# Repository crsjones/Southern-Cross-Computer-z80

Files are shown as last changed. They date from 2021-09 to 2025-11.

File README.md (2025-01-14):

# Southern Cross Computer

I developed the Z80 Southern Cross Computer for Hong Kong based Kitsrus in 1992/93.
The kit was based on the TEC-1 Computer that was designed by John Hardy and Ken Stone
in 1983 and appeared in Australia's Talking Electronics Magazine Issue 10 March 1983.

Kitsrus distributed the kit into the US and the UK and was sold online from Hong Kong.

The Southern Cross Computer appeared in Australia's Silicon Chip Magazine in the August 1993 edition.
A follow up article appeared in Silicon Chip in December 1993 describing the 8x8 LED Matrix and 8 Channel Relay add-on board.

There is a Facebook group for the Southern Cross SBC
[https://www.facebook.com/groups/1553416258519631)

### SC-8x8   8 x 8 LED Matrix
The original 8 x8 LED Matrix design plus a couple of revisions.
### SC-GBCART
An add-on board that connects a Gameboy FLASH cartridge to the Southern Cross SBC.
### SC-SERIAL 
A MC6850 serial board based on the Grant Searle 'Minimum System Z80' design.
### SC-APU
An add-on card for the AM9511A  Arithmetic Processor Unit.
### SC-MEM
Expansion memory board. 2x28 pin sockets for either 8kx8 or 32kx8 devices. 
### SC-CPU
Connect your expansion boards to this CPU board instead of the Southern Cross SBC!
### SC-BP
An expandable six slot backplane that connects to the SC expansion connector.

### SC-ALED
A hardware, parallel to serial PWM WS2812B addressable RGB LED driver board.

# Current Version

The current version of the Southern Cross PCB is 3.3, Gerbers are available in the SouthernCrossSBC_PCB_R33 folder.

The current version of the monitor is 1.8.
 Source code, listing, binary and INTEL hex files can be found in the SCMonitorV18 folder under the SouthernCrossSBC_Monitor folder.

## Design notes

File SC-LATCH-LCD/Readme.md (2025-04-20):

# Southern Cross LCD

Using a latch is a common way to connect to a LCD.
The schematic shows how to hook up a 2 line 16 character LCD (1602) to an eight bit latch.
You can hook it up to the SC I/O port at the top of the board or use IC1 to replace the multiplexed 7 segment display.

The code uses the same routines as the monitor uses for the seven segment display but outputs to the LCD instead, also sending the displayed
string out the serial port.
 
The code is a work in progress so the backlight control is currently not implemented and there 
are some additional functions needed to complete the LCD driver.

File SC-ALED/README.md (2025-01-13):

## SC-ALED

A parallel to serial converter to drive WS2812B ARGB's (Addressable RGB LED's) aka Neopixels.

This board simply accepts a byte from an I/O write and converts it to a serial bit stream of PWM pulses to set the colours in each ARGB in a string.

### SC-ALED-01Article.pdf
### SC-ALED-01ComponentOverlayBOM.pdf
### SC-ALED-01Schematic.pdf

## Folders

### ExampleCode
Code examples for the board using the SC SBC.

### Gerber
A zip file containing Gerber files for the Double-Sided TH PCB.

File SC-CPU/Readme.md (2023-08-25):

# Southern Cross CPU
A Z80 Microprocessor with a reset and oscillator circuit.
All of the Z80 pins are brought out to a 2x20 40 pin header and to a 40 pin socket for plugging into an
existing Z80 socket. A ZIF socket footprint is also provided.

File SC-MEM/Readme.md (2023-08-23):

# Southern Cross Memory Expansion

A memory expansion board that takes 2 x 28 pin devices, the board can be strapped to use
SRAM,EEPROM or EPROM devices, organised as either 8k x 8 or 32k x 8.
Decoding can be selected for each device, duplicating the memory decoding circuit on the main board for 8k decoding 
of the whole memory map or decoded as two 32k blocks.

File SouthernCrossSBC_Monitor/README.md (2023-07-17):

# Southern Cross Computer Monitor

The current version of the monitor is 1.8. 
 Source code, listing, binary and INTEL hex files can be found in the SCMonitorV18 folder under the SouthernCrossSBC_Monitor folder.
The Monitor will work on any version of the Southern Cross PCB and on the TEC-1F and also supports a software scanned keyboard
 if the out of production 74C923 keyboard encoder cannot be sourced.

It can be conditionally built for the following boards:

### SC18-SC
This is the version for a Southern Cross with a 74C923 keyboard encoder.
### SC18-SC-SS
This is the version for a Southern Cross with software scanned keyboard mods.
### SC18-TEC-1F
This is the version for the TEC-1F with a 74C923 keyboard encoder.
### SC18-TEC-1F-SS
This is the version for the TEC-1F with software scanned keyboards mods.

The source file was assembled using TASM32. There is an include (SCM18_Include.asm) file that defines all the Monitor variables 
that can be used in your own programs, an short example of its use is also included in the folder (SCMTest.asm)

### SCMonitorV18_ACIA
A version of the 1.8 Monitor has been patched with the ACIA code from the SC-6850_Serial\Code folder to work with the 6850 ACIA
instead of the Bit Bang Serial Port, only the Source file is provided.

### SCNEO
Built with Buffered Interrupt driven serial communication using the SC-SERIAL ACIA Add-on board.

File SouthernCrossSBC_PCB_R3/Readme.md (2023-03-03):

#Southern Cross Version 3.0 PCB

Changes to Version 3.0 

1. Added extra holes for 6mm sq. tactile switches.
2. Re-spaced the 7 segment LEDs to allow for FND500/560 displays.
3. Replaced the Resistor network  SIL3 with individual resistors.
4. Replaced W02 bridge with individual 1N4002 diodes.
5. Replaced 0.85" pitch electrolytic capacitor pads with 0.1" pitch pads.
6. DIN1 goes to pin 15 IC 8 and DIN2 goes to pin 17 IC8, labels were swapped on original schematic.
7. Replaced speed switch with 0.1" pads.
8. Added 0.1" pitch 2 pin connector for 5V.
9. Added top layer pad for mounting holes.
10. Added keyboard legend to silk screen.

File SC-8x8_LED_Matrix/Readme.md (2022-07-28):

# Southern Cross 8 x 8 LED Matrix Display 

### SC-8x8_R2
The version produced by Kitsrus, 
this folder contains the original manual and code.

This original documentation was downloaded from the Quasar Electronics website.

https://quasarelectronics.co.uk/Item/sc04-8x8-display-board

### SC-8x8_R3 
This version was just a redo of the original circuit on a smaller PCB, designed 
to fit behind the display.

### SC-8x8_R4 
The manual contains the schematic, bill of material(s) and component overlay.

PCB Gerbers are provided for this version.

The code is from the original distribution disk and can be assembled using TASM.

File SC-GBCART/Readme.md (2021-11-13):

# Southern Cross GB Cart Adapter

Some bootleg GameBoy cartridges use 4M FLASH chips and 32k SRAM's.
They can be connected directly to the Z80 buses and can be re-flashed using one of the GameBoy  
flashers that are available.

As the cartridge maps across most of the memory map you need to remove the EEPROM and 
RAM from the Southern Cross, you can however connect the EEPROM and RAM socket to the 
undecoded areas of the memory map $8000-$9FFF, $C000- $DFFF and $E000-$FFFF.
You could use both sockets with RAM  with some small modifications to the PCB. 
This will give a total of 24k bytes of RAM in the memory map, with 8k banked as described below.

The Gerbers for the PCB are provided, remember to specify the PCB as 0.8mm thick otherwise the IDC
 connector won't fit over the edge of the PCB.

The information about the cart was supplied to the TEC-1 Z80 Facebook group by Ben Grimmett;
He sells the Flash Cartridges on his website;  https://bennvenn.myshopify.com/

4M FLASH / 32K (NVRAM) SRAM cartridge. MBC5 Mapper.

Memory map:

0x0000-0x3FFF:    16kBytes - fixed to Flash Address 0x0000-0x3FFF

0x4000-0x7FFF:    16kBytes - 4MBytes in 256 banks, swapped by writing to address 0x2000.

0xA000-0xBFFF:    8kBytes - 32kBytes in 8k banks, swapped by writing to 0x4000.

                 Write protected unless 0x0A written to 0x0000. Protected if any other value is written to that address.

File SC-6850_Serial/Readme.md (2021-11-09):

# Southern Cross Serial

This circuit is based on the “Minimum chip count z80 computer” design by Grant Searle and is commonly used in the RC2014 project.

Here it has been adapted for the Southern Cross Computer adding the expansion connector, I/O decoding, 
and a header for a FTDI USB to serial converter.

Version 2  has an additional jumper to disconnect the INT interrupt signal from the processor, the CLK INT jumper has been

renamed OSC. Some designators have been renamed.

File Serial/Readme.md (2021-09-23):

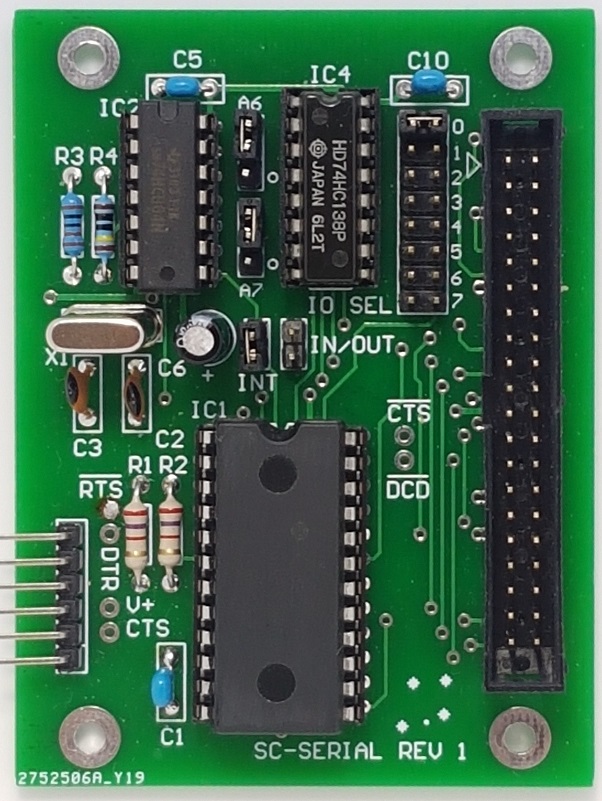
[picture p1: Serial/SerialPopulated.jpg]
SC Serial Board


# Southern Cross Serial

This circuit is based on the “Minimum chip count z80 computer” design by Grant Searle and is commonly used in the RC2014 project.

Here it has been adapted for the Southern Cross Computer adding the expansion connector, I/O decoding, 
and a header for a FTDI USB to serial converter.

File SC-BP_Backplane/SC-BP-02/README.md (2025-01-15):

## SC-BP Six Slot Backplane 

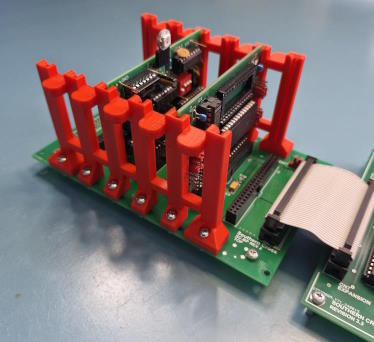
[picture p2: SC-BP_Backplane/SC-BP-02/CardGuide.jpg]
Southern Cross Backplane


The Backplane board allows the expansion of the Southern Cross SBC, the 40 way Box header on the main board brings out all of the Z80 pins.

You can also use the backplane with the processor board, a expansion memory board and a serial port board to create a stand-alone "rack" system.

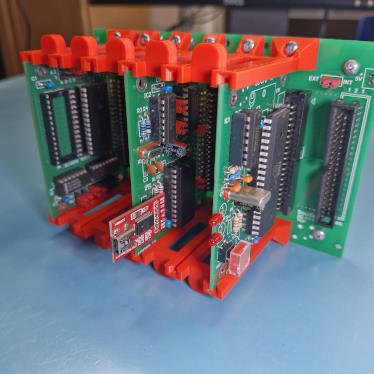
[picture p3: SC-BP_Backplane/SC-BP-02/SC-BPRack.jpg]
Southern Cross Rack Mount


Included in this folder is the .STL file for the card guide.

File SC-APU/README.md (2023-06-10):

### SC-APU

This add-on board was created for Stephen Justin of the TEC-1 Facebook group https://www.facebook.com/groups/tec1z80 and
inspired by Philip Stevens' RC2014 APU https://github.com/RC2014Z80/RC2014/tree/master/Hardware/APU%20RC2014

There are two code examples, the first, SC-LLL-FP is a purely software demonstration of the "Lawrence Livermore Laboratory Floating Point Package".
I have a separate repository with more info about this code.

The second code example, AM9511A uses the APU to perform basic arithmetic operations.
To run the code on the APU you need to be using the Southern Cross Monitor 1.8 as it uses the monitor system calls.

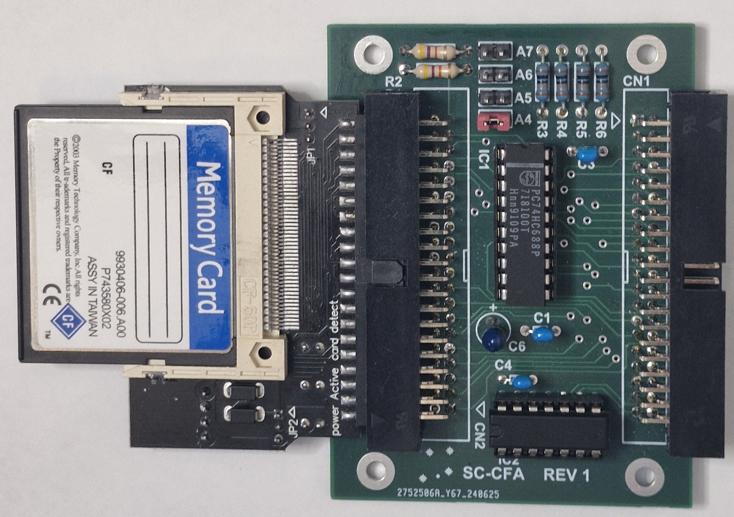
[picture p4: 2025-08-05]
SC-CF/CardwithCF.jpg

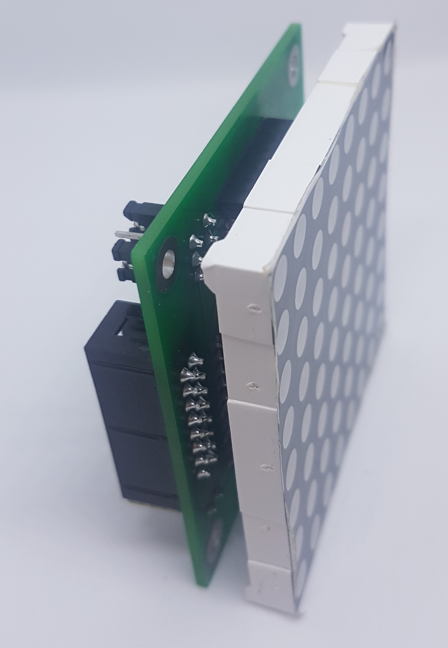
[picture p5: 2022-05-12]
SC-8x8_LED_Matrix/SC-8x8_R3/SC-8x8-R3-1.jpg

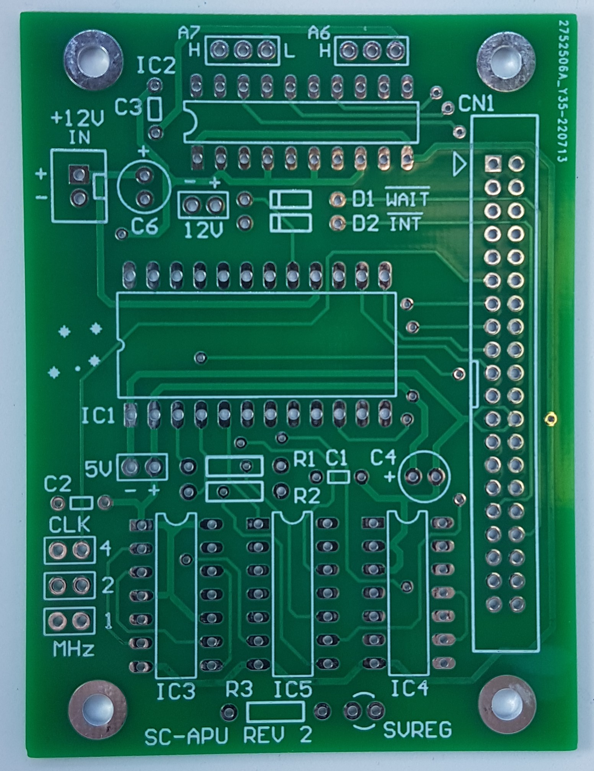
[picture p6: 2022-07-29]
SC-APU/SC-APU-R2/SC-APU-R2_PCB.jpg

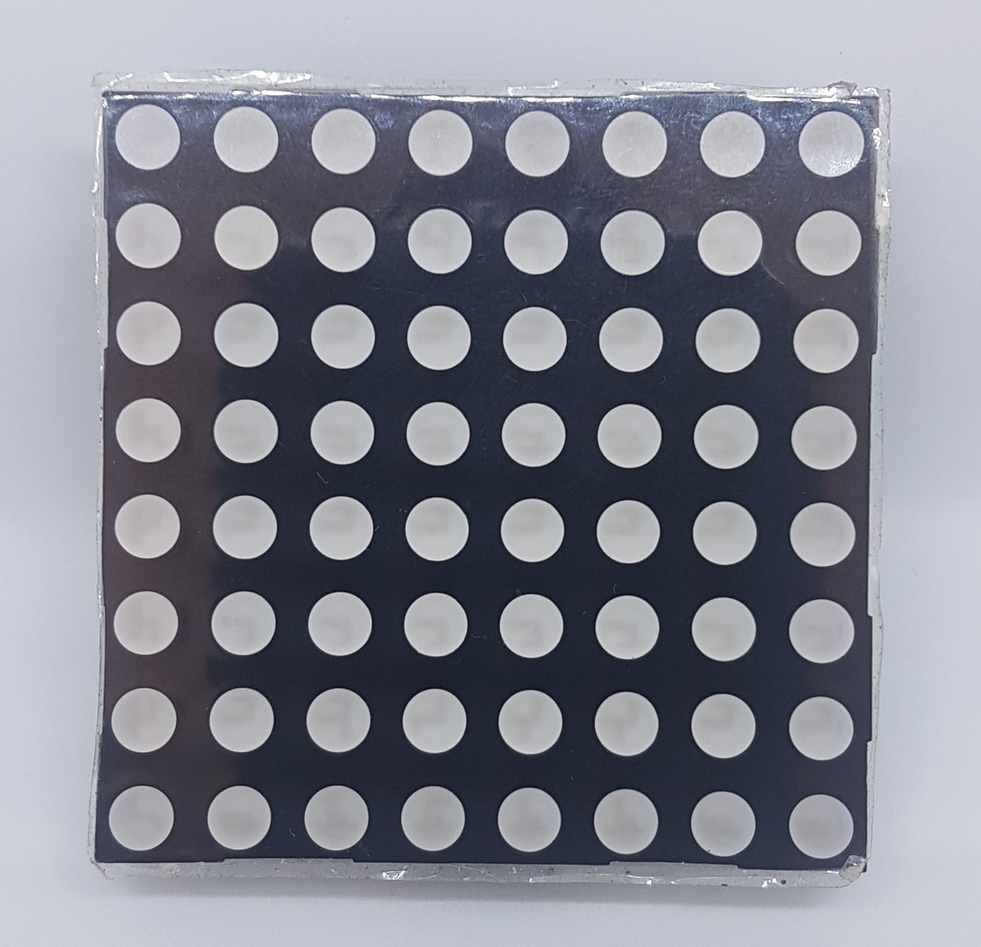
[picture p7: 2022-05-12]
SC-8x8_LED_Matrix/SC-8x8_R3/SC-8x8-R3-2.jpg

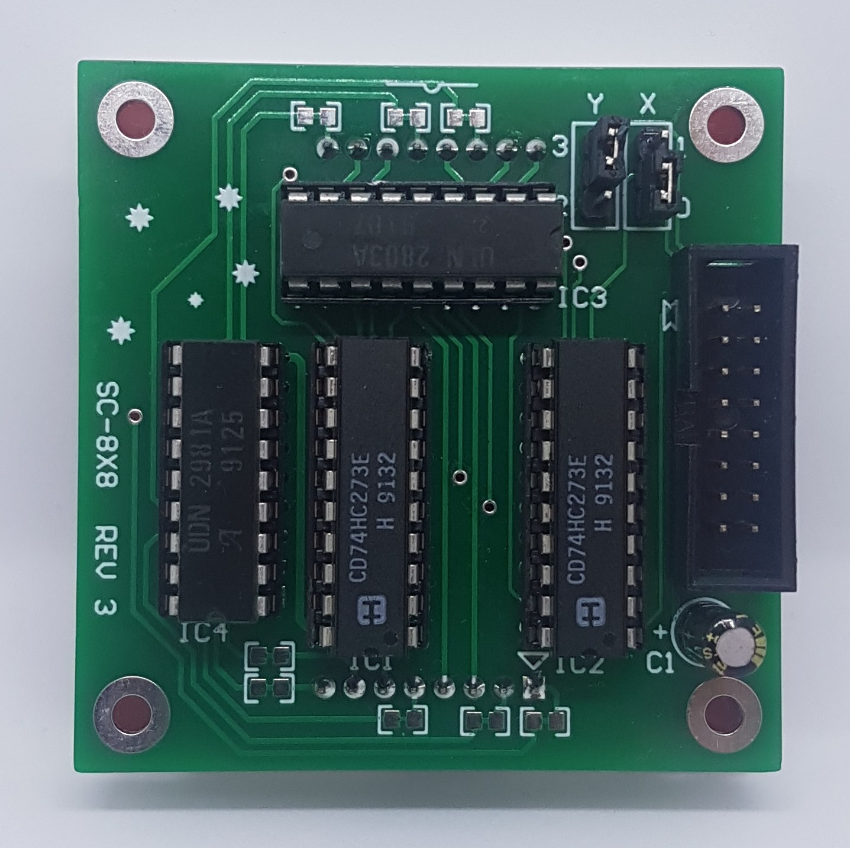
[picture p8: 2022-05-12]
SC-8x8_LED_Matrix/SC-8x8_R3/SC-8x8-R3.jpg

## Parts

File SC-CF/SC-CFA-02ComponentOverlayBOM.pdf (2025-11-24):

## SC-CFA Compact Flash Adapter Rev. 2

## Component Overlay

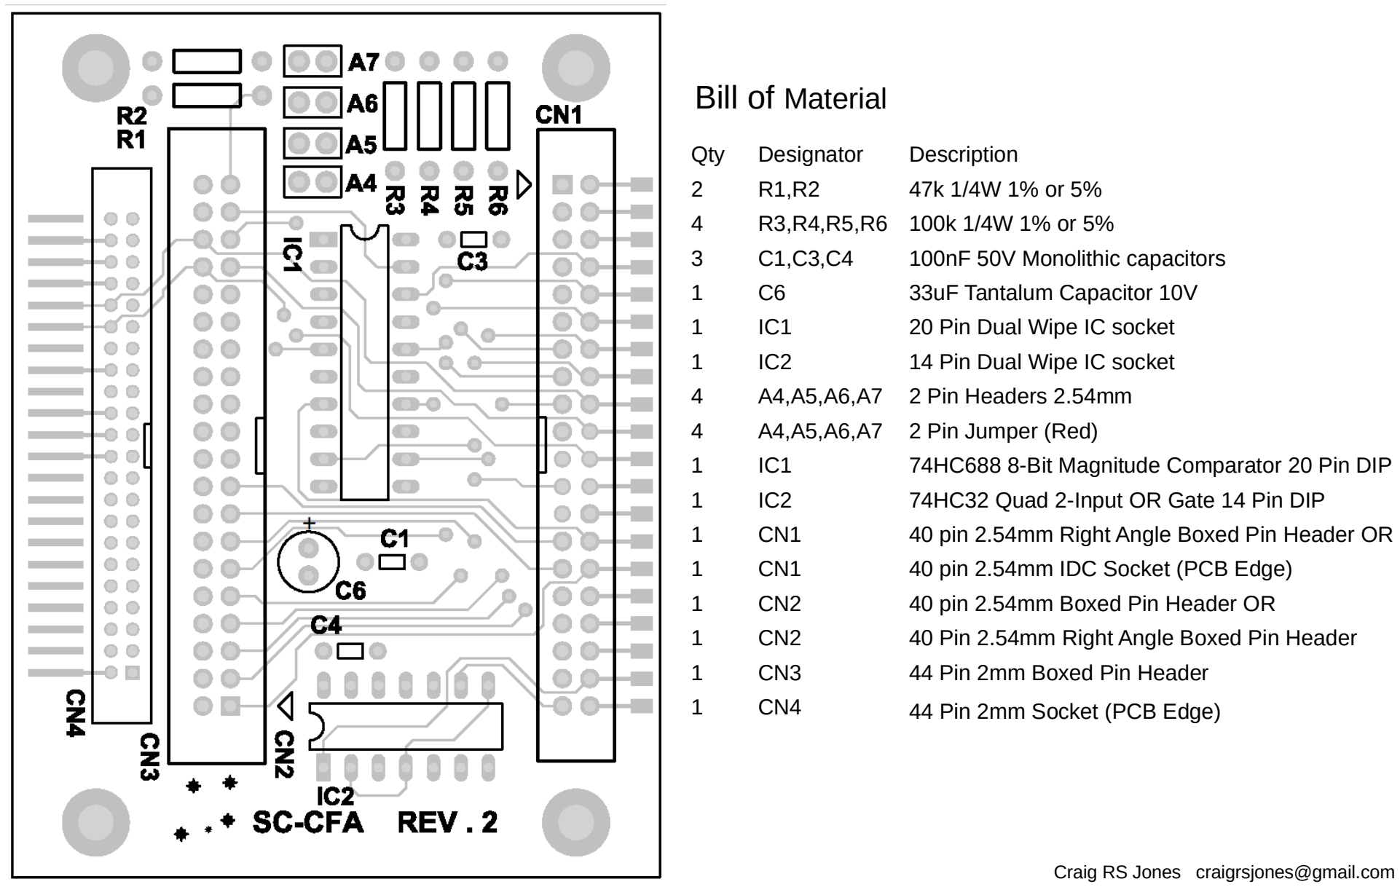
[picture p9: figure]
Bill of Material; Craig RS Jones craigrsjones@gmail.com; Qty; Designator; Description; 100nF 50V Monolithic capacitors; 33uF Tantalum Capacitor 10V; 20 Pin Dual Wipe IC socket; 14 Pin Dual Wipe IC socket; 2 Pin Headers 2.54mm; 2 Pin Jumper (Red); 40 pin 2.54mm Boxed Pin Header OR; 44 Pin 2mm Boxed Pin Header; 44 Pin 2mm Socket (PCB Edge)

1 | IC1 | 74HC688 8-Bit Magnitude Comparator 20 Pin DIP
1 | IC2 | 74HC32 Quad 2-Input OR Gate 14 Pin DIP
1 | CN1 | 40 pin 2.54mm Right Angle Boxed Pin Header OR
1 | CN1 | 40 pin 2.54mm IDC Socket (PCB Edge)
1 | CN2 | 40 Pin 2.54mm Right Angle Boxed Pin Header

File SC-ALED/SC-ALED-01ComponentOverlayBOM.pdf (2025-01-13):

## SC-ALED Addressable LED Interface Rev. 1

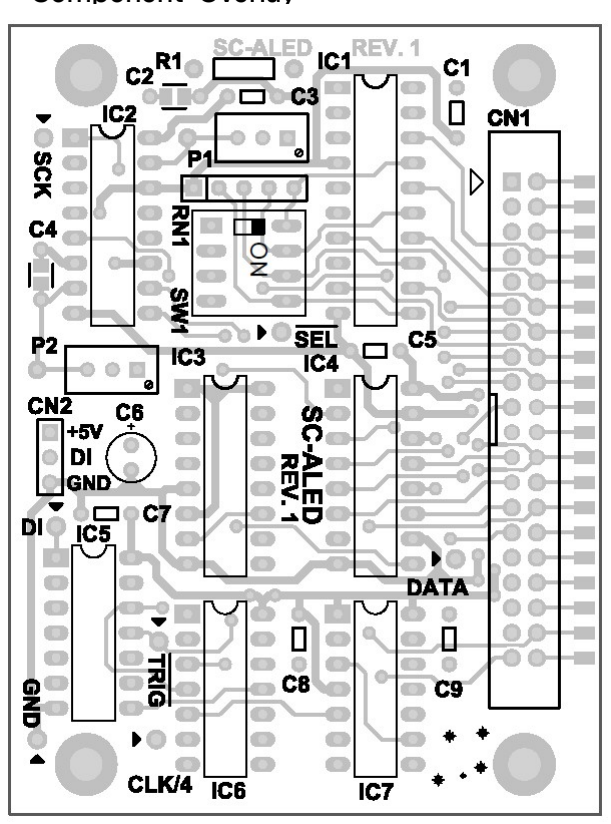
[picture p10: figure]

Component Overlay | Bill of Material

craigrsjones@gmail.com

Qty | Designator | Description
1 | R1 | 100R 1/4W 5% Resistor
1 | P1 | 2k2 1/4W 1% Resistor OR 10 Turn Trimpot 10k Bourns 3296 or Equivalent
1 | P2 | 5k6 1/4W 1% Resistor OR 10 Turn Trimpot 10k Bourns 3296 or Equivalent
1 | RN1 | Resnet 5 pin, 4 Commoned 100k Resistors SIL5
6 C1,C3,C5,C7, | C8,C9 | 100nF 50V X7R Monolithic Ceramic Capacitors (MLCC) 5mm Pitch
2 | C2,C4 | 100pF 50V 5% NPO/C0G MLCC Capacitor 0805 SMD OR 5mm Through Hole (TH)
1 | C6 | 10uF 50V Electrolytic Capacitor 2.54mm Pitch
1 | IC1 | 20 Pin Dual Wipe IC Socket
3 | IC2,IC3,IC4 | 16 Pin Dual Wipe IC Socket
3 | IC5,IC6,IC7 | 14 Pin Dual Wipe IC Socket
1 | IC1 | 74HC688 8-Bit Magnitude Comparator 20 Pin DIP
1 | IC2 | 74HC221 Dual Monostable 16 Pin DIP
1 | IC3 | 74HC161 Synchronous Binary Counter DIP 16
1 | IC4 | 74HC165 8-Bit Parallel Load Shift Register DIP 16
1 | IC5 | 74HC02 Quad 2-Input NOR Gate DIP 14
1 | IC6 | 74HC00 quad 2-Input NAND Gate DIP 14
1 | IC7 | 74HC74 Dual D Flip-Flop 14 Pin DIP
1 | SW1 | 4-Way DIP Switch
1 | CN1 | 40 pin 2.54mm Right Angle Boxed Pin Header
1 | CN2 | 3 Way R/A Pin Header

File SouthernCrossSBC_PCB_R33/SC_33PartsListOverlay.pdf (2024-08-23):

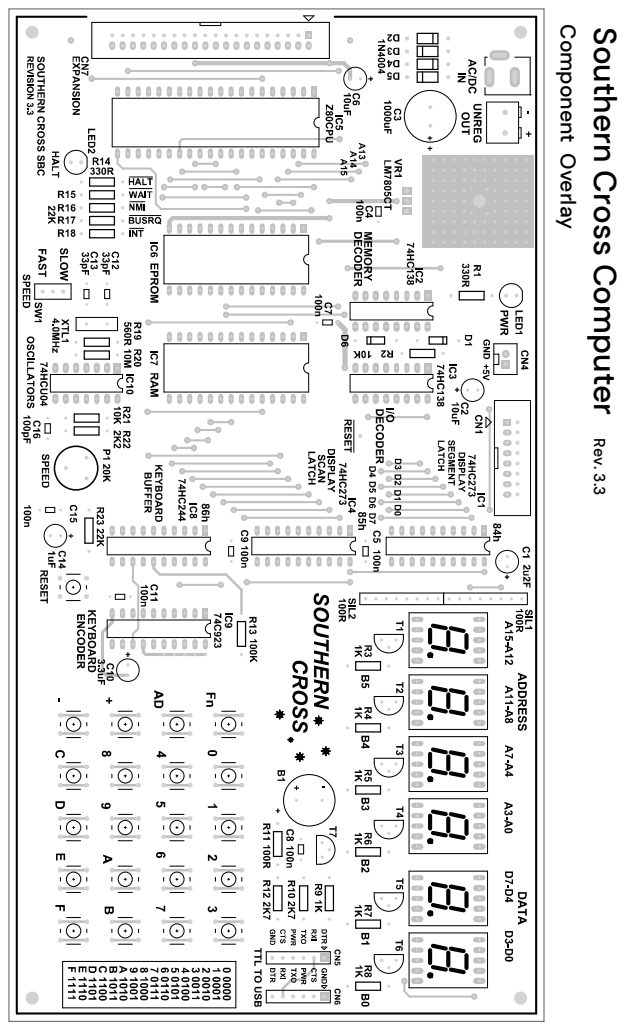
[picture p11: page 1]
Component Overlay

Southern Cross Computer Rev. 3.3

## Bill of Material

# Southern Cross Computer Rev. 3.3

Connued

Qty | Designator | Description
2 | R1,R14 | 330R ¼ W 5% Resistor
1 | R2,R21 | 10k ¼ W 5% Resistor
7 | R3,R4,R5,R6,R7,R8,R9 | 1k ¼ W 5% Resistor
2 | R10,R12 | 2k7 ¼ 5%W Resistor
1 | R11 | 100R ¼ W 5% Resistor
1 | R13 | 100k ¼ W 5% Resistor
5 | R15,R16,R17,R18,R23 | 22k ¼ W 5% Resistor
1 | R19 | 560R ¼ W 5% Resistor
1 | R20 | 10M ¼ W 5% Resistor
1 | R22 | 2k2 ¼ W 5% Resistor
2 | SIL1,SIL2 | 100R Resistor Network 8 Pin 4 Individual Resistors
4 | D2,D3,D4,D5 | 1N4004 Diode
2 | D1,D6 | 1N4148, 1N914 Small Signal Diode
1 | IC10 | 14 Pin Dual Wipe IC Socket
2 | IC2,IC3 | 16 Pin Dual Wipe IC Socket
4 | IC1,IC4,IC8,IC9 | 20 Pin Dual Wipe IC Socket
2 | IC6,IC7 | 28 Pin Dual Wipe IC Socket
1 | IC5 | 40 Pin Dual Wipe IC Socket
1 | C1 | 2u2F 50V Electrolytic Capacitor
2 | C2,C6 | 10uF 50V Electrolytic Capacitor
1 | C3 | 1000uF 35V Electrolytic Capacitor
7 | C4,C5,C7,C8,C9,C11,C15 | 100nF 50V Monolithic Ceramic Capacitor
1 | C10 | 3u3F 50V Electrolytic Capacitor
2 | C12,C13 | 33pF 50V Monolithic Ceramic Capacitor
1 | C14 | 1uF 50V Electrolytic Capacitor
1 | C16 | 100pF 50V Monolithic Ceramic Capacitor
7 | T1,T2,T3,T4,T5,T6,T7 | NPN Transistor BC337 40V TO-92 General Purpose
6 | LD1,LD2,LD3,LD4,LD5,LD6 | 0.56” 7 Segment LED Display, Common Cathode
2 | LED1,LED2 | 3mm Red LED
1 | CN1 | Straight Box Header, 16 Way 2 x 8 Rows
1 | CN2 | Power Jack for Barrel Connector O.D. 5.5 / I.D. 2.1 mm
1 | CN3 | 2 Way Screw Terminal Block
1 | CN4 | 2 Way 0.1” / 2.54mm Pin Header
1 | CN5 or CN6 | 6 Way 0.1” / 2.54mm Pin Header
1 | CN7 | Straight Box Header 40 Way 2 x 20 Rows
1 | SW1 | 3 Way 0.1” / 2.54mm Pin Header + Shunt

Bill of Material Continued

# Southern Cross Computer Rev. 3.3

NOTES:
1. Designators Increment from the top left to right, top to bottom of the PCB.

### 2. The MM74C923 is obsolete and no longer manufactured, however they can still be found

on Ebay.
Alternatively you can use the software scanned keyboard built into the monitor and not use a MM74C923 at all. There is a modification procedure in this folder.
Qty | Designator | Description
21 S1,S2,S3,S4,S5,S6,S7,S8,S9, | S10,S11,S12,S13,S14,S15,S16, S17,S18,S19,S20,S21 | Pushbuttons, Tactile Switch OMRON B3F 6mm
1 | P1 | 20k VTP Cermet Trimpot
1 | B1 | Mini Magnetic Transducer 0.25” 6.35mm
1 | VR1 | LM7805CT 5V Fixed Voltage Regulator TO-220
1 | XTL1 | 4MHz Crystal HC49 / HC49U
1 | VR1 | TO-220 Heatsink 19 x 15 x 10 mm M3x8 Machine Screw Zn, M3 Hex Nut Zn, M3 split washer.
2 | IC1,IC4 | 74HC273 Octal D Flip-Flops with Clear
2 | IC2,IC3 | 74HC138 3-to-8 Line Decoder
1 | IC5 | Z84C0008PEG CMOS Z80 CPU 8MHz 40 pin DIP
1 | IC6 | AT28C64B-15PU 8k x 8 DIP28 EEPROM
1 | IC7 | 6264 8k x 8 DIP28 SRAM
1 | IC8 | 74HC244 Octal TRI-STATE Buffer DIP20
1 | IC9 | MM74C923N 20 Key Keyboard Encoder DIP20
1 | IC10 | 74HCU04 Hex Inverter
1 | PCB | PCB Southern Cross SBC Revision 3.3

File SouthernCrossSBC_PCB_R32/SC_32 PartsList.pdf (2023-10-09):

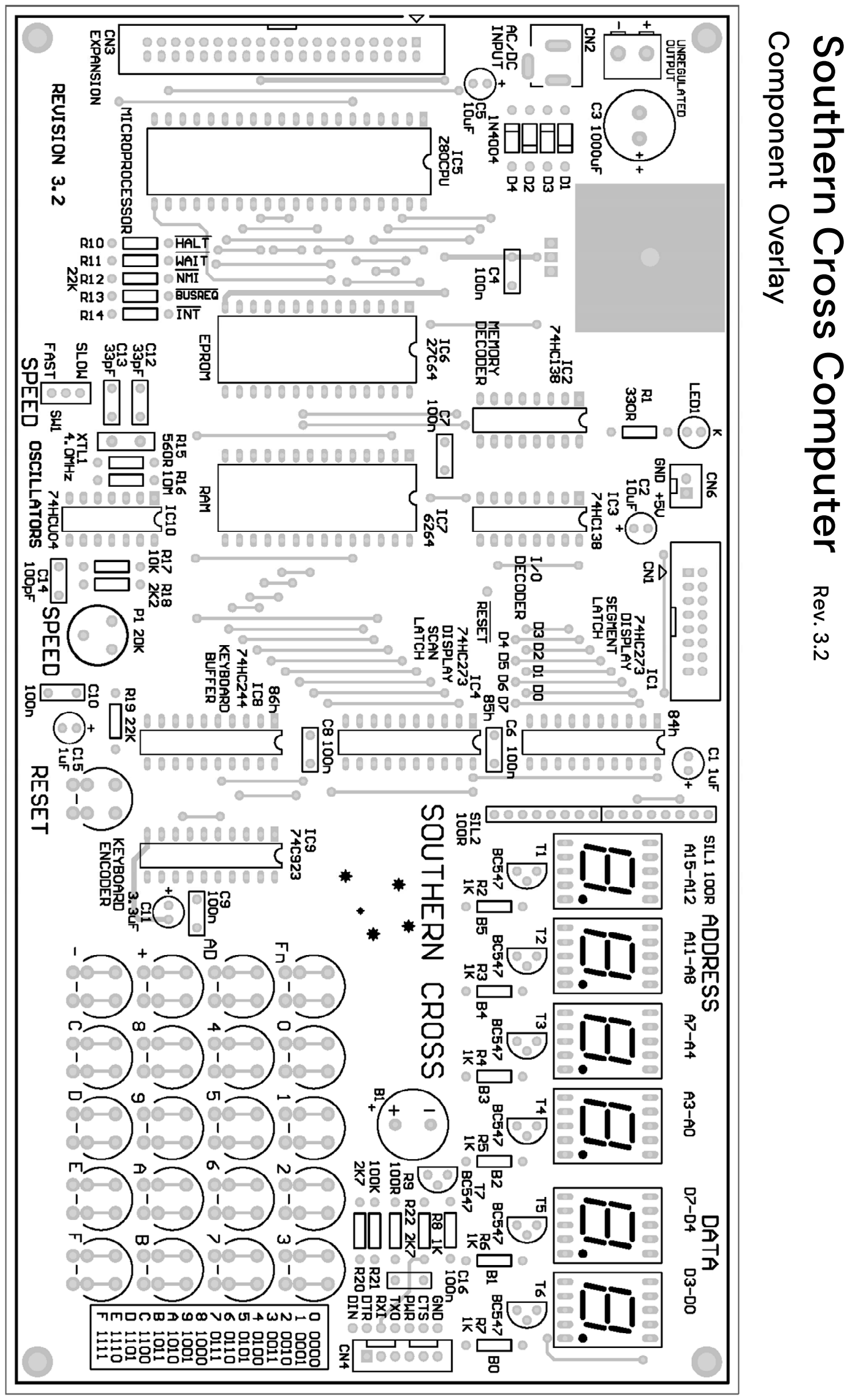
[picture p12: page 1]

# Southern Cross Computer Rev. 3.2

## Component Overlay

## Bill of Material

# Southern Cross Computer Rev. 3.2

Qty | Designator | Description
1 | R1 | 330R 1/4W Resistor
7 | R2,R3,R4,R5,R6,R7,R8 | 1k 1/4W Resistor
1 | R9 | 100R 1/4W Resistor
6 | R10,R11,R12,R13,R14,R19 | 22k 1/4W Resistor
1 | R15 | 560R 1/4W Resistor
1 | R16 | 10M 1/4W Resistor
1 | R17 | 10k 1/4W Resistor
1 | R18 | 2k2 1/4W Resistor
2 | R20,R22 | 2k7 1/4W Resistor
1 | R21 | 100k 1/4W Resistor
4 | D1,D2,D3,D4 | 1N4004 Diode
1 | IC10 | 14 Pin Dual Wipe IC Socket
2 | IC2,IC3 | 16 Pin Dual Wipe IC Socket
4 | IC1,IC4,IC8,IC9 | 20 Pin Dual Wipe IC Socket
2 | IC6,IC7 | 28 Pin Dual Wipe IC Socket
1 | IC5 | 40 Pin Dual Wipe IC Socket
2 | C1,C15 | 1uF 0.1” / 2.54mm
2 | C2,C5 | 10uF 25V
1 | C3 | 1000uF 25V / 35 V
7 | C4,C6,C7,C8,C9,C10,C16 | 100nF 50V
1 | C11 | 3u3F 63V
2 | C12,C13 | 33pF Monolithic Ceramic 100V
1 | C14 | 100pF Monolithic Ceramic 100V
6 | LD1,LD2,LD3,LD4,LD5,LD6 | 0.56” 7 Segment LED Display, Common Cathode
7 | T1,T2,T3,T4,T5,T6,T7 | NPN Transistor TO-92 General Purpose
1 | CN1 | Straight Box Header, 16 Way 2 x 8 Rows
1 | CN2 | Power Jack for Barrel Connector O.D. 5.5 / I.D. 2.1 mm
1 | CN3 | Straight Box Header 40 Way 2 x 20 Rows
1 | CN4 | 6 Way 0.1” / 2.54mm Pin Header
1 | CN5 | 2 Way Screw Terminal Block
1 | CN6 | 2 Way 0.1” / 2.54mm Pin Header
1 | SW1 | 3 Way 0.1” / 2.54mm Pin Header + Shunt

Connued

Qty | Designator | Description
21 S1,S2,S3,S4,S5,S6,S7,S8,S9, | S10,S11,S12,S13,S14,S15,S16, S17,S18,S19,S20,S21 | Pushbuttons, Tactile Switch OMRON B3F 6mm or C&K Momentary Keyswitch D6 5mm
2 | SIL1,SIL2 | 4 x 100R Isolated Resistor Network 8 Pin SIL (Single In Line) or 4 x 100R 1/4W Resistor mounted upright
1 | LED1 | 3mm Red LED
1 | P1 | 20k Trimpot
1 | B1 | Mini Magnetic Transducer 0.25” 6.35mm
1 | VR1 | LM7805CT 5V Fixed Voltage Regulator TO-220
1 | XTL1 | 4MHz Crystal HC49 / HC49U
1 | HS1 | TO-220 Heatsink M3x10 Machine Screw Zn, M3 Hex Nut Zn, M3 split washer.
2 | IC1,IC4 | 74HC273 Octal D Flip-Flops with Clear
2 | IC2,IC3 | 74HC138 3-to-8 Line Decoder
1 | IC5 | Z80 CPU
1 | IC6 | 27C64 8k x 8 EPROM or AT28C64A EEPROM
1 | IC7 | 6264 8k x 8 SRAM
1 | IC8 | 74HC244 Octal TRI_STATE Buffer
1 | IC9 | MM74C923N 20 Key Keyboard Encoder *Note3
1 | IC10 | 74HCU04 Hex Inverter

Bill of Material Continued

# Southern Cross Computer Rev. 3.2

NOTES:
1. Designators Increment from the top left to right, top to bottom of the PCB. (apart from the additional resistors added to this version R20, R21, R22 which are
located near CN4)
2. Voltage Regulator VR1 is loaded on the top of the PCB above C4.

### 3. The MM74C923 is obsolete and no longer manufactured, however they can still be found

on Ebay.
Alternatively you can use the software scanned keyboard built into the monitor and not use a MM74C923 at all. There is a modification procedure for the board in the docs folder.

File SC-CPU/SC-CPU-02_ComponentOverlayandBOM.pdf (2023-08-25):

# SC-CPU Rev. 2

Component Overlay | Bill of Material

Craig RS Jones craigrsjones@gmail.com

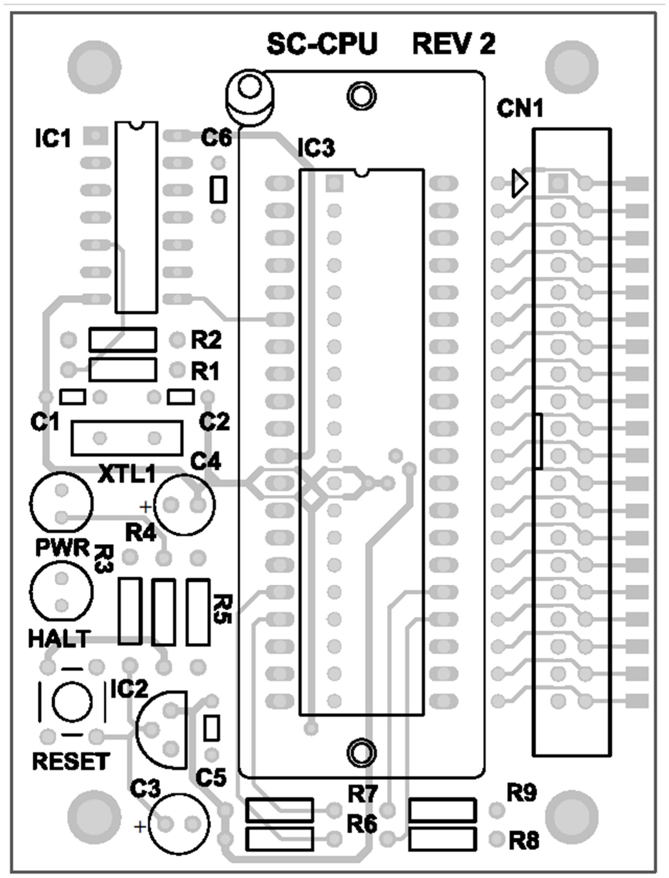
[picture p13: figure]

There are many construction options possible for this PCB, see the schematic for information on the Oscillator and Reset options. Multiple Optional components are listed here.

Qty | Designator | Description
1 | R1 | 10M 1/4W 1% or 5% (not critical)
1 | R2 | 560R 1/4W 1% or 5% (not critical)
1 | R3 | 22k 1/4W 1% or 5% (not critical)
1 | R4,R5 | 330R 1/4W 1% or 5% (not critical)
4 | R6,R7,R8,R9 | 10k 1/4W 1% or 5% (not critical)
2 | C1,C2 | 33pF 100V Ceramic capacitor 0.2” pitch
1 | C3 | 1uF RB 16vW Electrolytic Capacitor 0.1” pitch
1 | C4 | 10uF RB 16vW Electrolytic Capacitor 0.1” pitch
2 | C5,C6 | 100nF 50V Monolithic capacitors
1 | XTL1 | 4.0MHz Crystal HC49/HC49U
1 | IC1 | 14 pin Dual Wipe IC socket
1 | IC1 | 74HCU04 Hex Unbuffered Inverter 14 Pin DIP
1 | IC1 | 14 Pin Oscillator Module
1 | IC1 | 8 Pin Oscillator Module
1 | IC2 | DS1233-5 5V EconoReset TO-92
1 | IC3 | 40 Pin Dual Wipe IC socket
1 | IC3 | 40 Pin ZIF socket
2 | IC3 | 20 Pin Header strip (2 x 20 pins)
1 | IC3 | Z80 CPU 40 Pin DIP
1 | CN1 | 40 way Straight or R/A IDC box header
1 | RESET | Tactile Switch OMRON B3F 6mm
2 | PWR,HALT | 3mm / 5mm Red LED

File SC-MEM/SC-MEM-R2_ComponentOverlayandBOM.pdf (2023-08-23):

# SC-MEM Expansion Memory Rev. 2

Component Overlay | Bill of Material

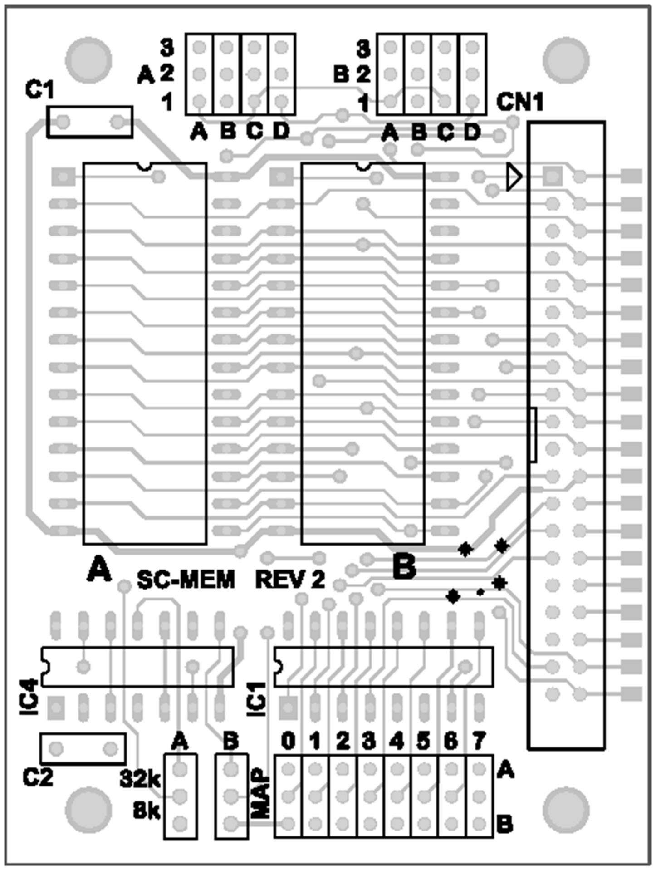
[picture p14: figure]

Craig RS Jones craigrsjones@gmail.com

Qty | Designator | Description
2 | C1,C2 | 100nF 50V Monolithic capacitors
1 | CN1 | 40 way Straight or R/A IDC box header
1 | IC1 | 16 pin Dual Wipe IC socket (optional)
1 | IC1 | 74HC138 3 to 8-line decoder 16 pin DIP
2 | IC2,IC3 | 28 pin Dual Wipe IC socket
1 | IC4 | 14 pin Dual Wipe IC socket
1 | IC4 | 74HC04 Hex Inverter DIP 14
2 J4,J5 | ‘Device Select’ | 4 x 3 Pin 0.1” pitch pin headers
1 J1 | ‘8k Memory Map Select’ | 8 x 3 pin 0.1” pitch pin headers
2 | J2,J3 | 1 x 3 pin 0.1” pitch pin headers

12 2 Pin Shunts

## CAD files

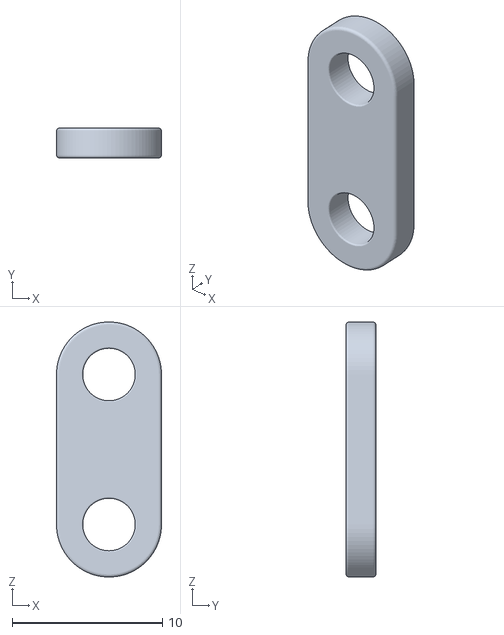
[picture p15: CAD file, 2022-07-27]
SC-8x8_LED_Matrix/SC-8x8_R4/Link.stl
7.00 x 2.00 x 17.0

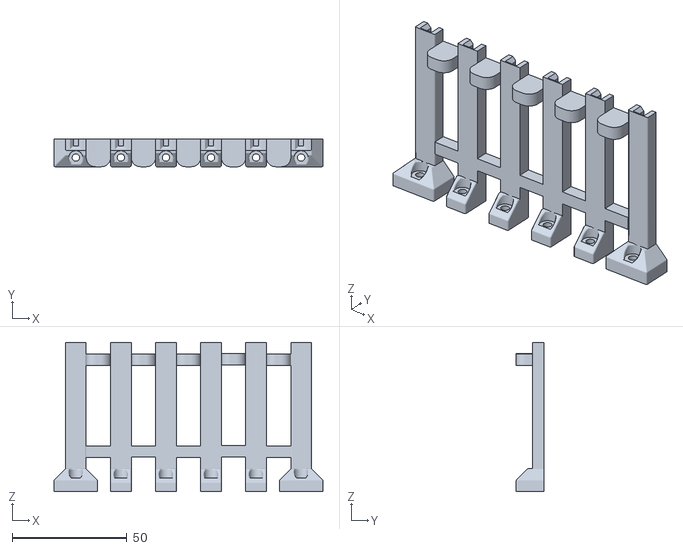
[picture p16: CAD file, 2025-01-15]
SC-BP_Backplane/SC-BP-02/SC-BPCardGuide.stl
117.0 x 12.0 x 65.0

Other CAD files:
SC-LATCH-LCD/SC-LatchLCD.obj

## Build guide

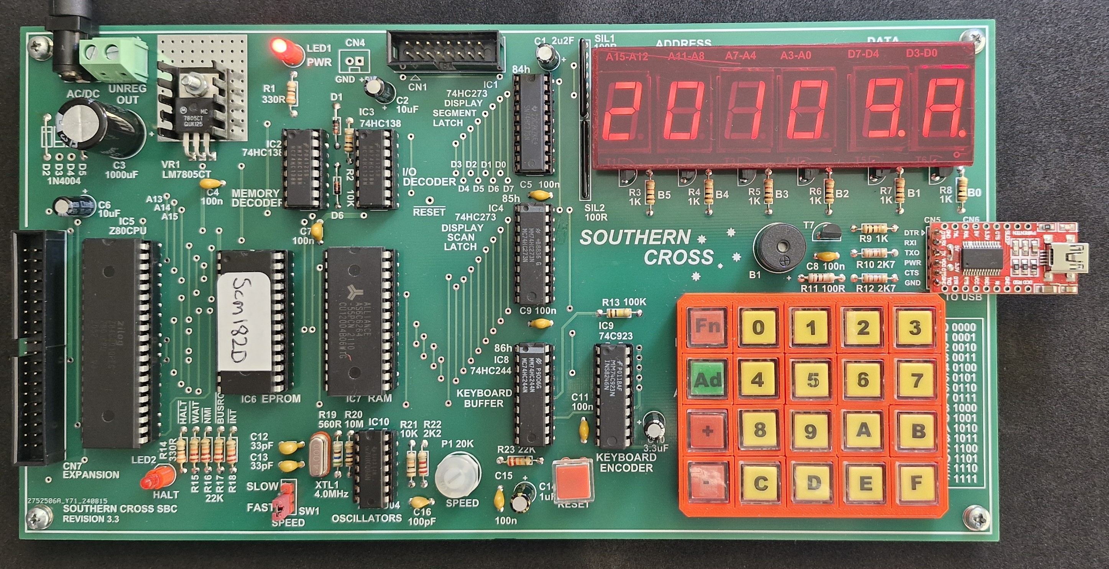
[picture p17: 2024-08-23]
SouthernCrossSBC_PCB_R33/SC33Assembled.jpg

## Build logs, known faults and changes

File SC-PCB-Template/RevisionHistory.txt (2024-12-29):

----------------------------------------------------------------------------------------------------------
2024-12-29  SC_Template_5

SC_footprint.pretty\EDGE40.kicad_mod
Removed stubs from edge connector component.
Increased pad sizes for pins 19 to 25 to 70mils up from 62 mils

SC_footprint.pretty\IDC40EDGE.kicad_mod
Removed stubs from combined IDC40EDGE edge connector component.
Increased pad sizes for pins 19 to 25 to 70mils up from 62 mils

SC_Template_5.kicad_Sch
Removed the picture of the SC expansion connector.
Renamed /BUSREQ as /BUSRQ
Renamed /BUSACK as /BUSAK

SC_Template_5.kicad_Pcb
Updated the footprints and the nets from the Schematic document to correct Net names and duplicate /BUSAK
---------------------------------------------------------------------------------------------------------

2024-12-30 SC-Template
Moved to Github repository

SC_Template.kicad_Pcb
Updated footprints to remove stubs.
---------------------------------------------------------------------------------------------------------

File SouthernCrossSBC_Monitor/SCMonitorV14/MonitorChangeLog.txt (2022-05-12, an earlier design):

Southern Cross Monitor Version 1.2
----------------------------------

Changes to Southern Cross Monitor Version 1.1   February, 1993.

1. When the Function Key is pressed twice, the routine jumps to the
address loaded at FUNJMP. It is set to CANCEL in the Fn routine and is
reloaded after Reset.

2. The table in the Function routine is now accessed by pointer FUNTBL
this will allow users to change the Function key assignments. It is set to
FUNLST (the Function key table) and is reloaded after Reset.

3. RAMCHK has been renamed as DALLAS as it is used in the Dallas
Smartwatch routines.

4. Read and write Smartwatch have had more explanation added to the
subroutine headers.

5. The Default serial BAUD rate is now 4800 Baud, which is reloaded after
Reset.

6. IO7 has been added as it is now used for the Single Stepper Hardware.

7. CALMDE has been added to the Smartwatch registers, if bit 7 is high the
calendar (Fn F) shows the date in MM/DD/YY mode, if bit 7 is low it is
shown in DD/MM/YY. This allows the setting of the date in the Smartwatch
to the country preference.

8. DELAYR has been renamed DELONE.

9. The Relay test program is now Fn D and not Fn 7.

10. Fn 7 is used to toggle the hardware single stepper if attached.It
displays a T in the rightmost Data display briefly to indicate the Trace
toggle.

11. All of the Relay code has been moved above to Fn D.
 (All the code for each function key is now in order).

12. Corrected spelling of 'Separate'

                      - - - - - - - - - - - - - - -

July, 1993.  Version 1.21
-------------------------

A buyer rang to point out that the relay test did not test all relays. We
found that a 05H instead of 55H at 0B7D in the Monitor was to blame. The
test was missing relay positions D4 and D6.

                      - - - - - - - - - - - - - - -

February 2003. Version 1.3  (This version was UNRELEASED)
--------------------------

The 74C923 code was removed and replaced with software scanned keyboard code.

1. Added SYSFLG at 3FB3H 'System Flags' 
Bit 1 is used to indicate the type of keyboard.
  
Bit 1 = 1 Software scanned keyboard.
Bit 1 = 0 Hardware scanned keyboard.

Initialization routine checks if DA is high ( software scanned keyboard
has DA tied high to allow for detection) and sets Bit 1 accordingly.

2. Added SCANKEY routine to scan keyboard, replaced all
 
IN      A,(KEYBUF) with 

with

CALL    SCANKEY

except for the increment/ decrement key handling which required some additional mods.
Added SCANKEY to system call jump table.

                      - - - - - - - - - - - - - - -

March 2021 Version 1.4
----------------------

1. Cleared SYSFLG on Reset and changed the keyboard flag to bit 0.

2. The receive INTEL hex routine did not work in the 1.3 version.
   The RXDATA routine had a cancel feature allowing a keypress to break out of the 'waiting for serial character' loop. 
   The SCANKEY routine takes a lot longer than IN  A,(KEYBUF) so the receive INTEL hex routine was now not fast enough to process incoming bytes.
   The cancel functionality was removed from the RXDATA routine, the receive INTEL hex routine now just returns to the monitor if the file download was
   successful.
   
3. The Receive INTEL Hex routine (INTELH) was made stand alone and added to the system call jump table so it could be called from outside the monitor.

                      - - - - - - - - - - - - - - -

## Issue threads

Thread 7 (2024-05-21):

APU chip select

b1ackmai1er, 2024-05-21:
Hi, On your APU R3 board, I think you should have nIORQ going to pin 3 of the LS688 not nMREQ. Regards Phil.

crsjones, 2024-05-21:
Hi Phil, No, the timing of chip select to the AM9511A is different to the Read Write timing.
If you look at the HC688 you will see that the output will only go low when there is a address match and /MREQ is High (P0 = Q0).
The /IOREQ  gates the /RD and /WR which controls the data transfer, /CS is already low before /IOREQ  as during this I/O cycle /MREQ is High.
You should look at Philip Stevens original circuit and description to satisfy yourself that this is correct.
Regards
Craig

b1ackmai1er, 2024-05-21:
Hi Craig, Thank you for your quick reply.
Thank you, I would never have figured this out, thinking that the /CS was standard 688 configuration. I was finding I could read from the chip but could not write to it. Back to the drawing board, track cutter, hookup wire and soldering iron. Cheers!

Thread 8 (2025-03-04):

8x8 LED matrix display type

Rev-3ng, 2025-03-04:
On the Southern Cross 8x8 Matrix display the BOM lists LD1 (8x8 LED matrix display) as a Common Anode type, while the schematic depicts a Common Cathode type.

crsjones, 2025-03-04:
I would agree that the schematic implies a common cathode display however the actual display (if ever described as such) is common anode.
The convention is to describe the display as common anode or common cathode according to the terminal connected, in common, to the rows.  This is what I found when revisiting the 8 x 8 display a few years ago and again just now.

My proposed remedy would be to also depict  a common row on the schematic and add a note to the documentation describing this difference.

Rev-3ng, 2025-03-04:
Hi Craig,I’m not too familiar with the 8x8 displays, common anode vs. common cathode. I probably should have looked into this before I posted the issue on your GitHub page. Sorry if I created a problem that may not exist.Is it the case that the 8x8 displays are both common anode and common cathode at the same time, at least for single colour LED displays. Or do the pin outs differ for each type such that the LEDs are backward in one type vs. the other so that they are not interchangeable. I have no idea.I only noticed this problem when I was about to order parts for three of your 8x8 boards that I purchased a while back that have been sitting around gathering dust. I’ve seen some advertised as common anode and others as common cathode on ebay or AliExpress.I did have one red 8x8 display in my pile of parts, but only to find that the pin pitch is 0.2” and not 0.1” as required on the 8x8 matrix boards. I didn’t even realise there were different types until then.Anyway hope I haven’t reacted too soon and maybe I’m raising an issue that has a simple answer in case others have the same question.Cheers,Mark C. Sent from my iPad 9th genOn 4 Mar 2025, at 21:56, Craig RS Jones ***@***.***> wrote:
  I would agree that the schematic implies a common cathode display however the actual display (if ever described as such) is common anode.
The convention is to describe the display as common anode or common cathode according to the terminal connected, in common, to the rows.  This is what I found when revisiting the 8 x 8 display a few years ago and again just now.
My proposed remedy would be to also depict  a common row on the schematic and add a note to the documentation describing this difference.—Reply to this email directly, view it on GitHub, or unsubscribe.You are receiving this because you authored the thread.Message ID: ***@***.***>

crsjones left a comment (crsjones/Southern-Cross-Computer-z80#8)
I would agree that the schematic implies a common cathode display however the actual display (if ever described as such) is common anode.
The convention is to describe the display as common anode or common cathode according to the terminal connected, in common, to the rows.  This is what I found when revisiting the 8 x 8 display a few years ago and again just now.
My proposed remedy would be to also depict  a common row on the schematic and add a note to the documentation describing this difference.

—Reply to this email directly, view it on GitHub, or unsubscribe.You are receiving this because you authored the thread.Message ID: ***@***.***>

crsjones, 2025-03-13:
Mark,
I have revised the 8x8 schematic to show all of the diodes in the 8x8 matrix, added a pinout diagram and a note about how to  identify a common anode or common cathode display.

Closed 2025-03-13.

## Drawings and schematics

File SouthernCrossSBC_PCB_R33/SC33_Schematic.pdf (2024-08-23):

## EXPANSION CONNECTOR

## I/O CONNECTOR

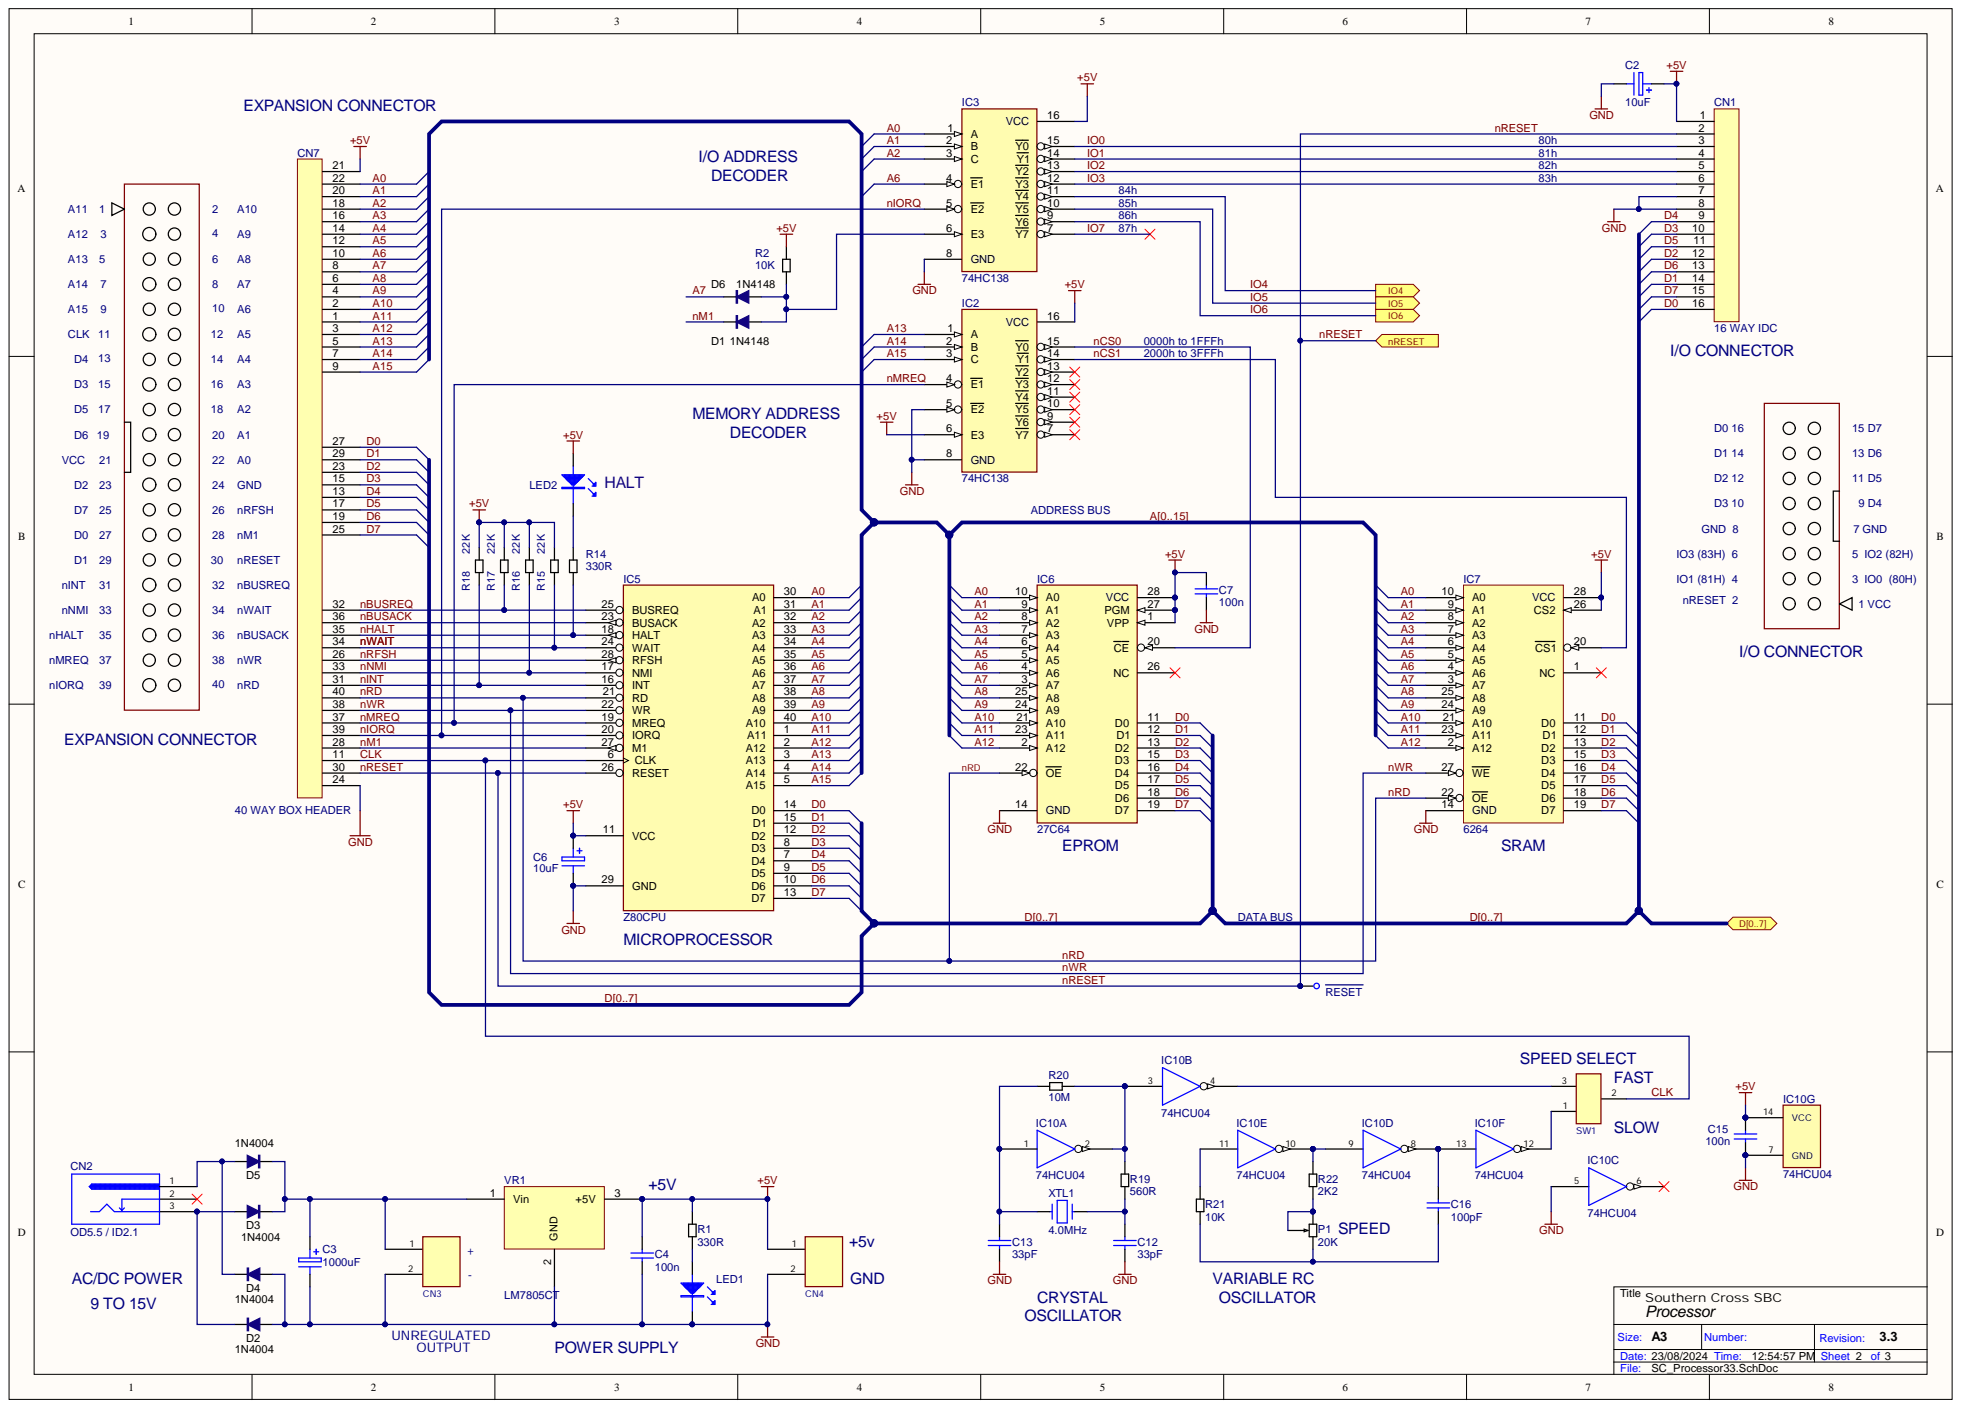
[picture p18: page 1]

ADDRESS | DATA

84h

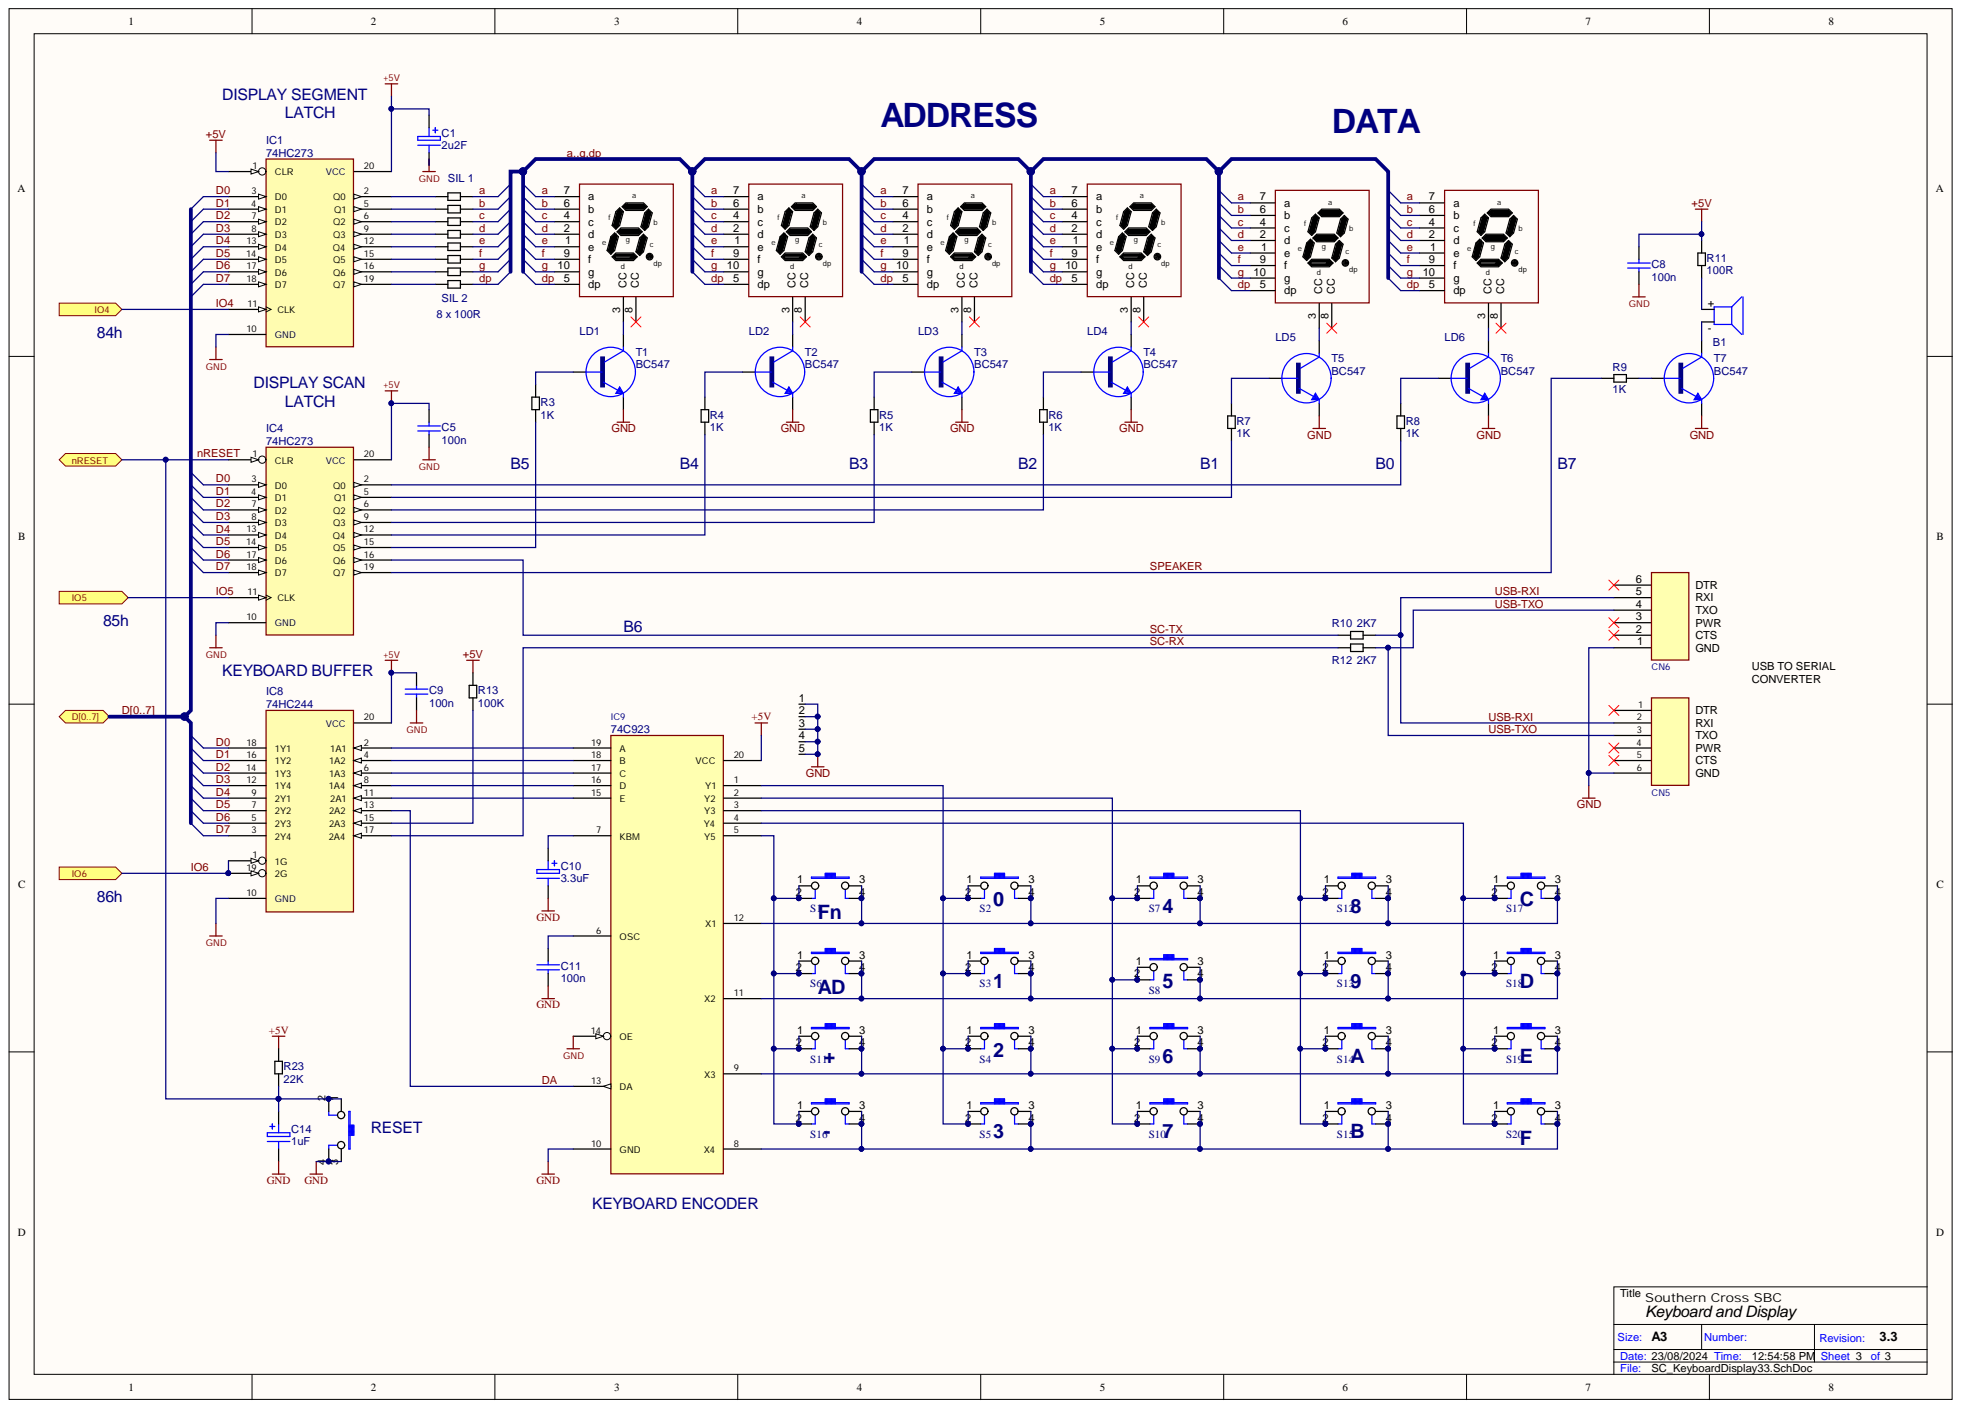
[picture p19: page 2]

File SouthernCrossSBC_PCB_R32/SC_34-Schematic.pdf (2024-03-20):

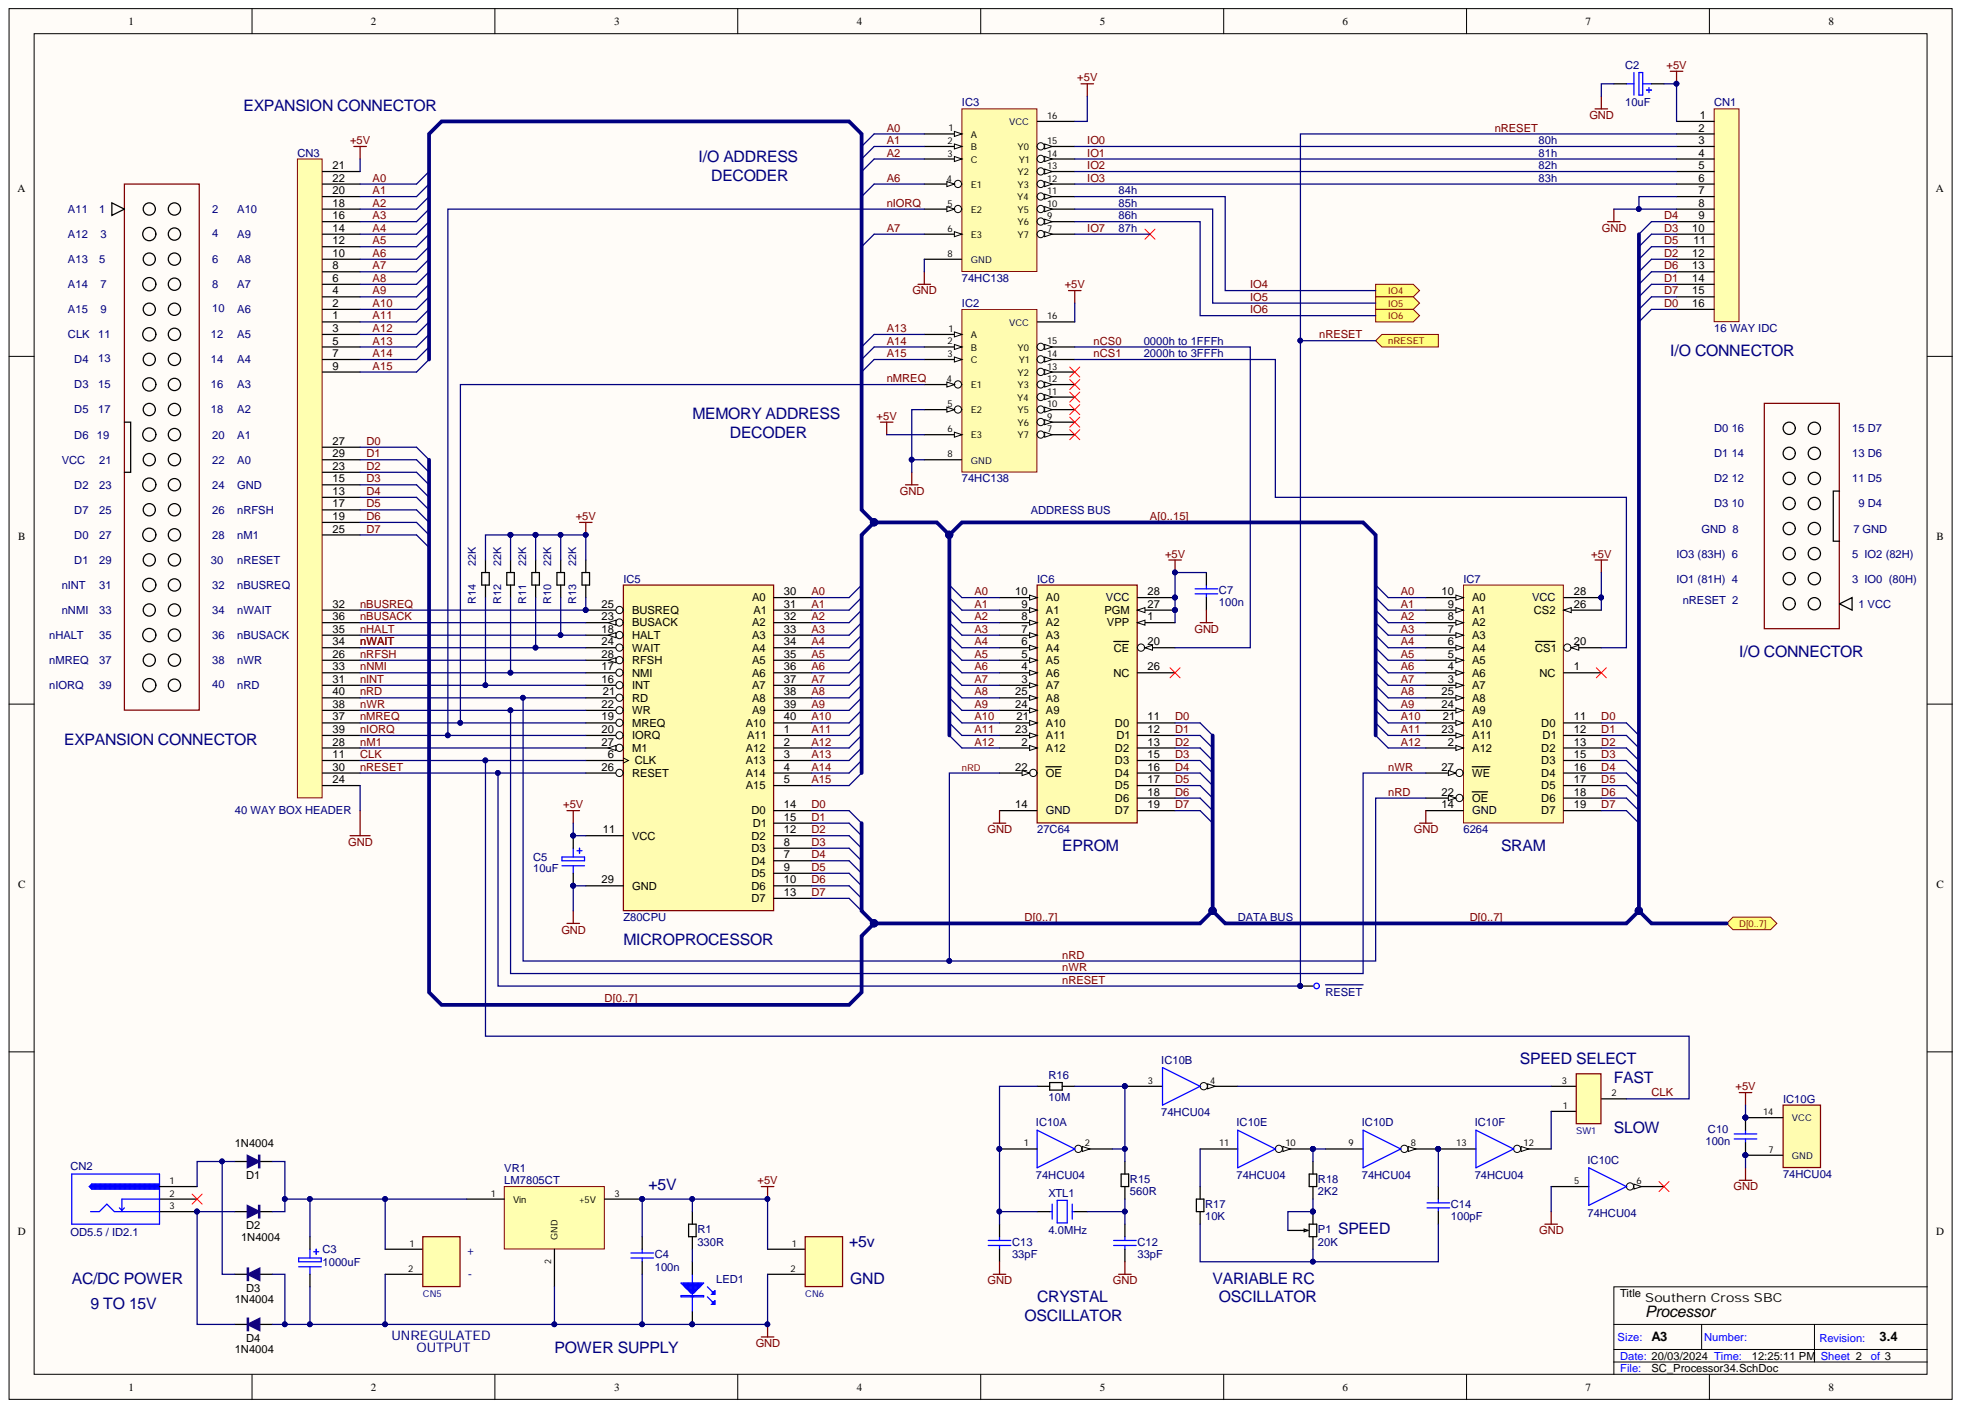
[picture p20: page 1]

A7 A13 A14 A15 nMREQ | E3 6 GND 8 | | 86h

IO5
IO6

Size: A3 | Number: | Revision: 3.4
Date: 20/03/2024 Time: 12:25:11 PM | | Sheet 2 of 3

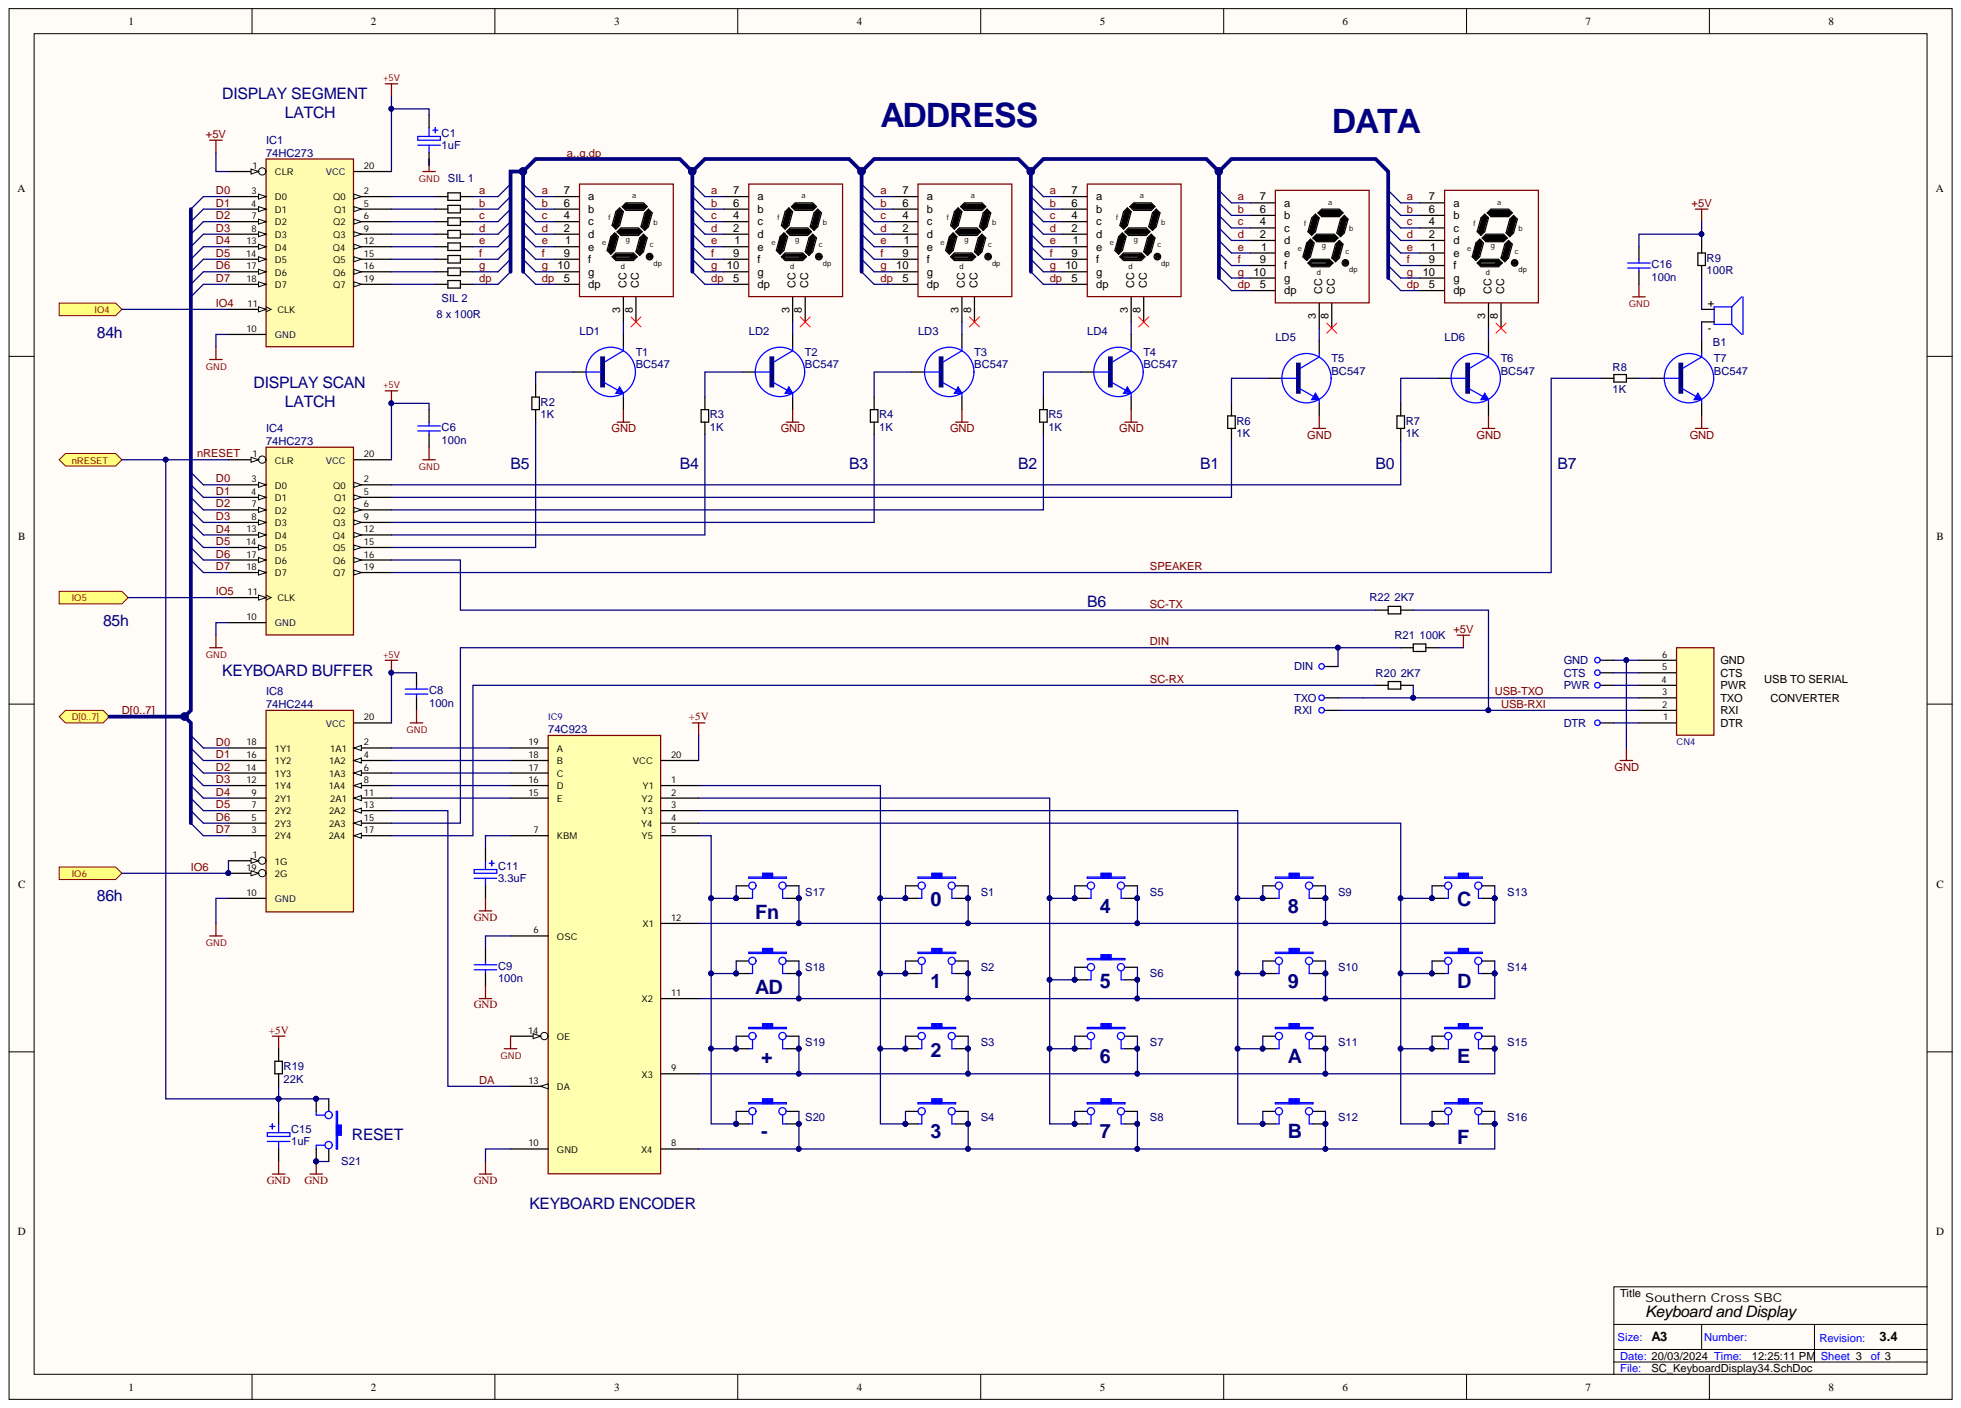
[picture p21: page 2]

CLR 1

SPEAKER

Size: A3 | Number: | Revision: 3.4
Date: 20/03/2024 Time: 12:25:11 PM | | Sheet 3 of 3

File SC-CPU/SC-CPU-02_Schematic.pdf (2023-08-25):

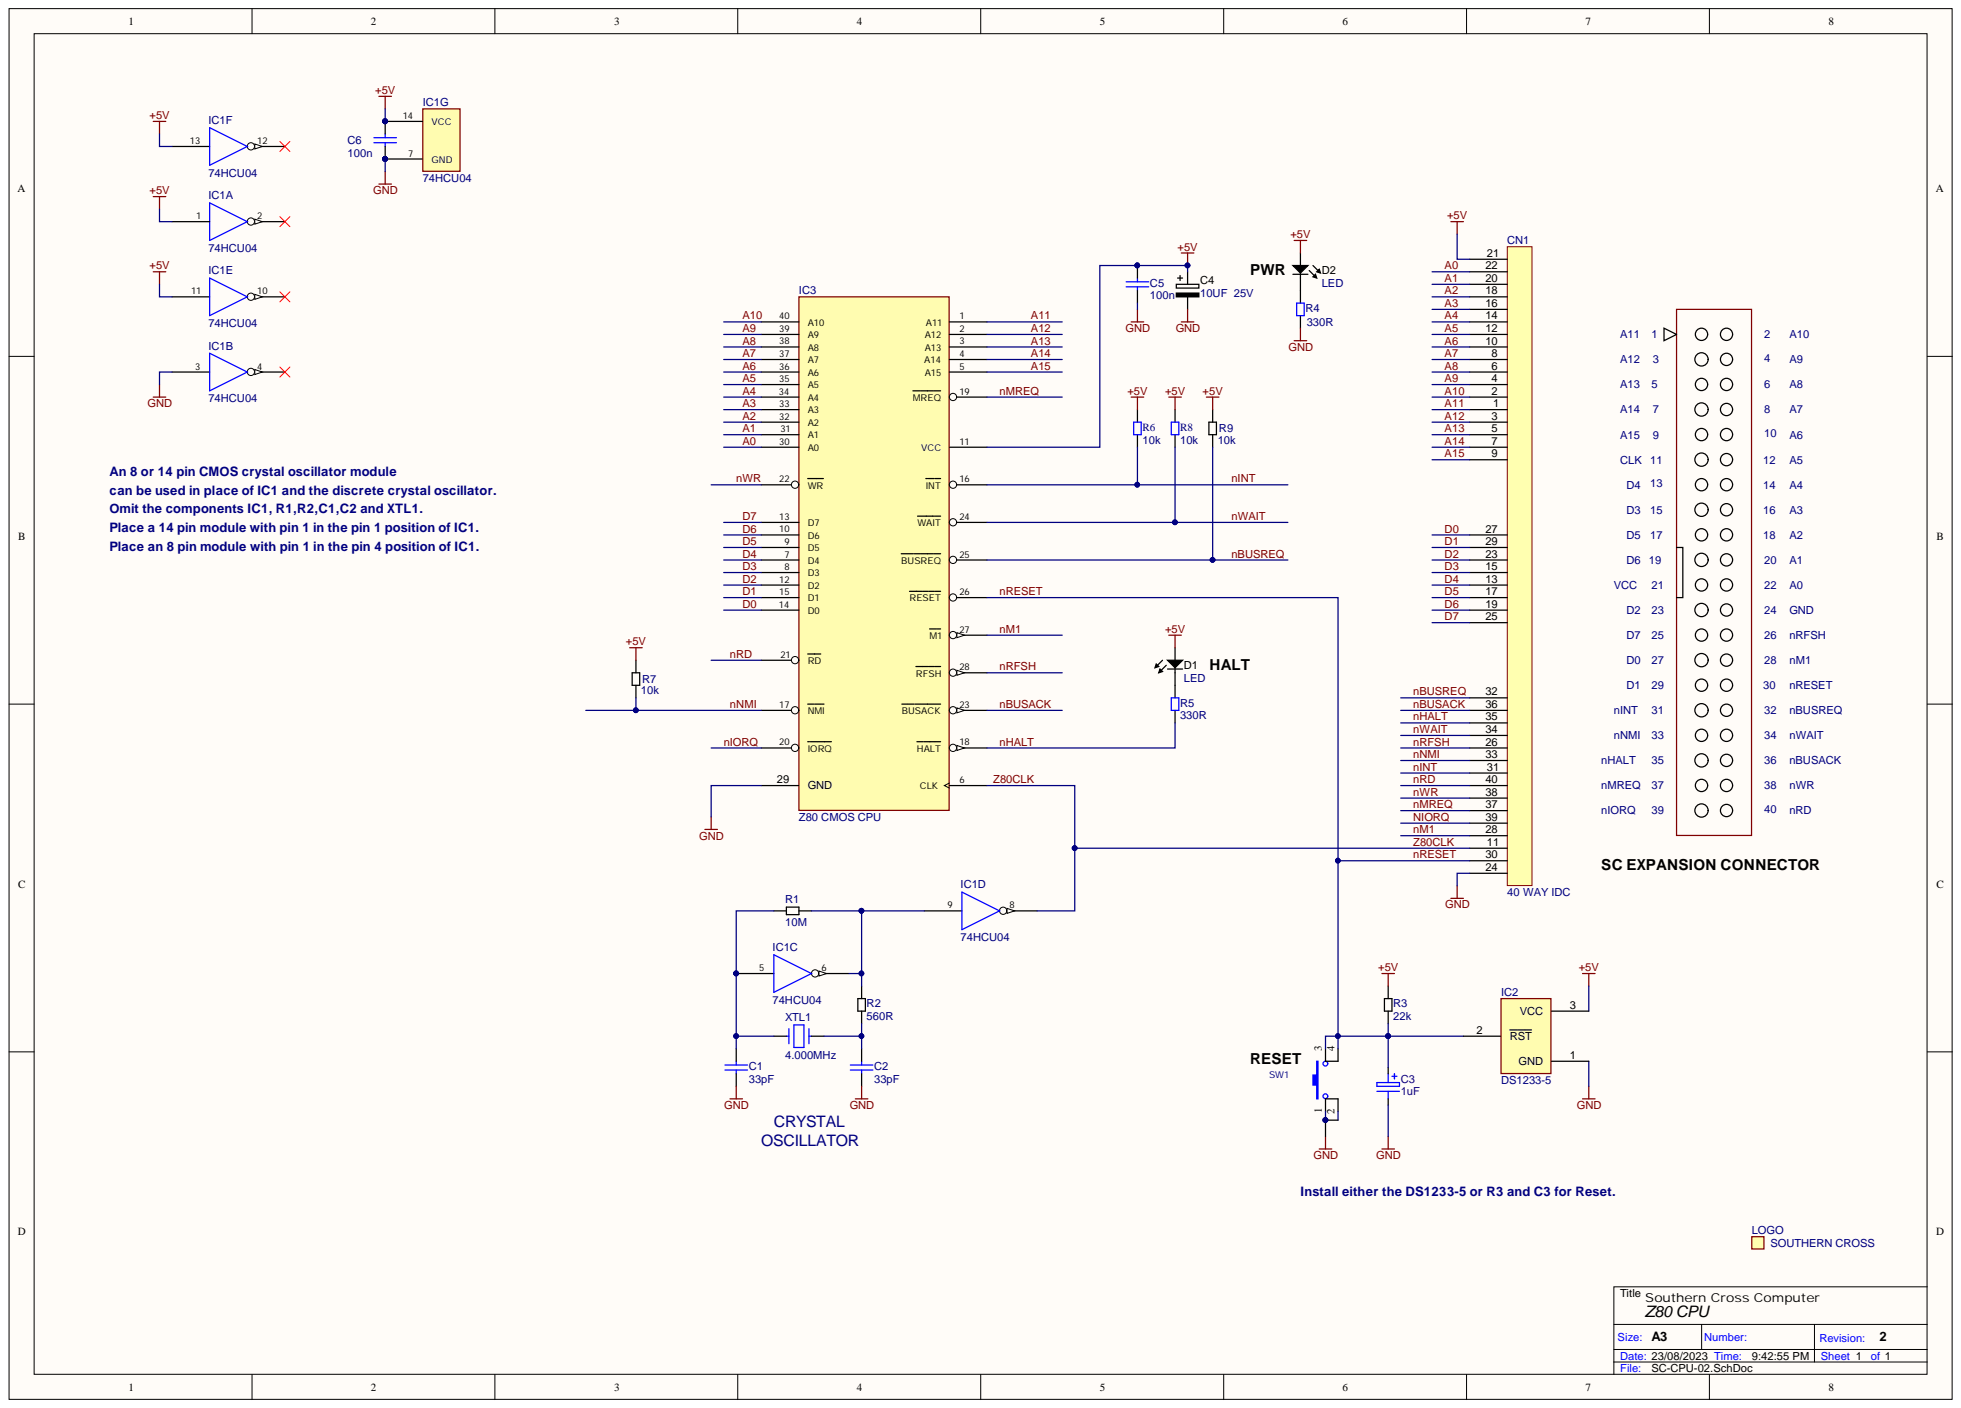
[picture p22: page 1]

An 8 or 14 pin CMOS crystal oscillator module
can be used in place of IC1 and the discrete crystal oscillator.
Omit the components IC1, R1,R2,C1,C2 and XTL1.
Place a 14 pin module with pin 1 in the pin 1 position of IC1.
Place an 8 pin module with pin 1 in the pin 4 position of IC1.

nRESET

nM1 +5V nRFSH D1 HALT

nRESET | 30

Install either the DS1233-5 or R3 and C3 for Reset.

Size: A3 | Number: | Revision: 2
Date: 23/08/2023 Time: 9:42:55 PM | | Sheet 1 of 1

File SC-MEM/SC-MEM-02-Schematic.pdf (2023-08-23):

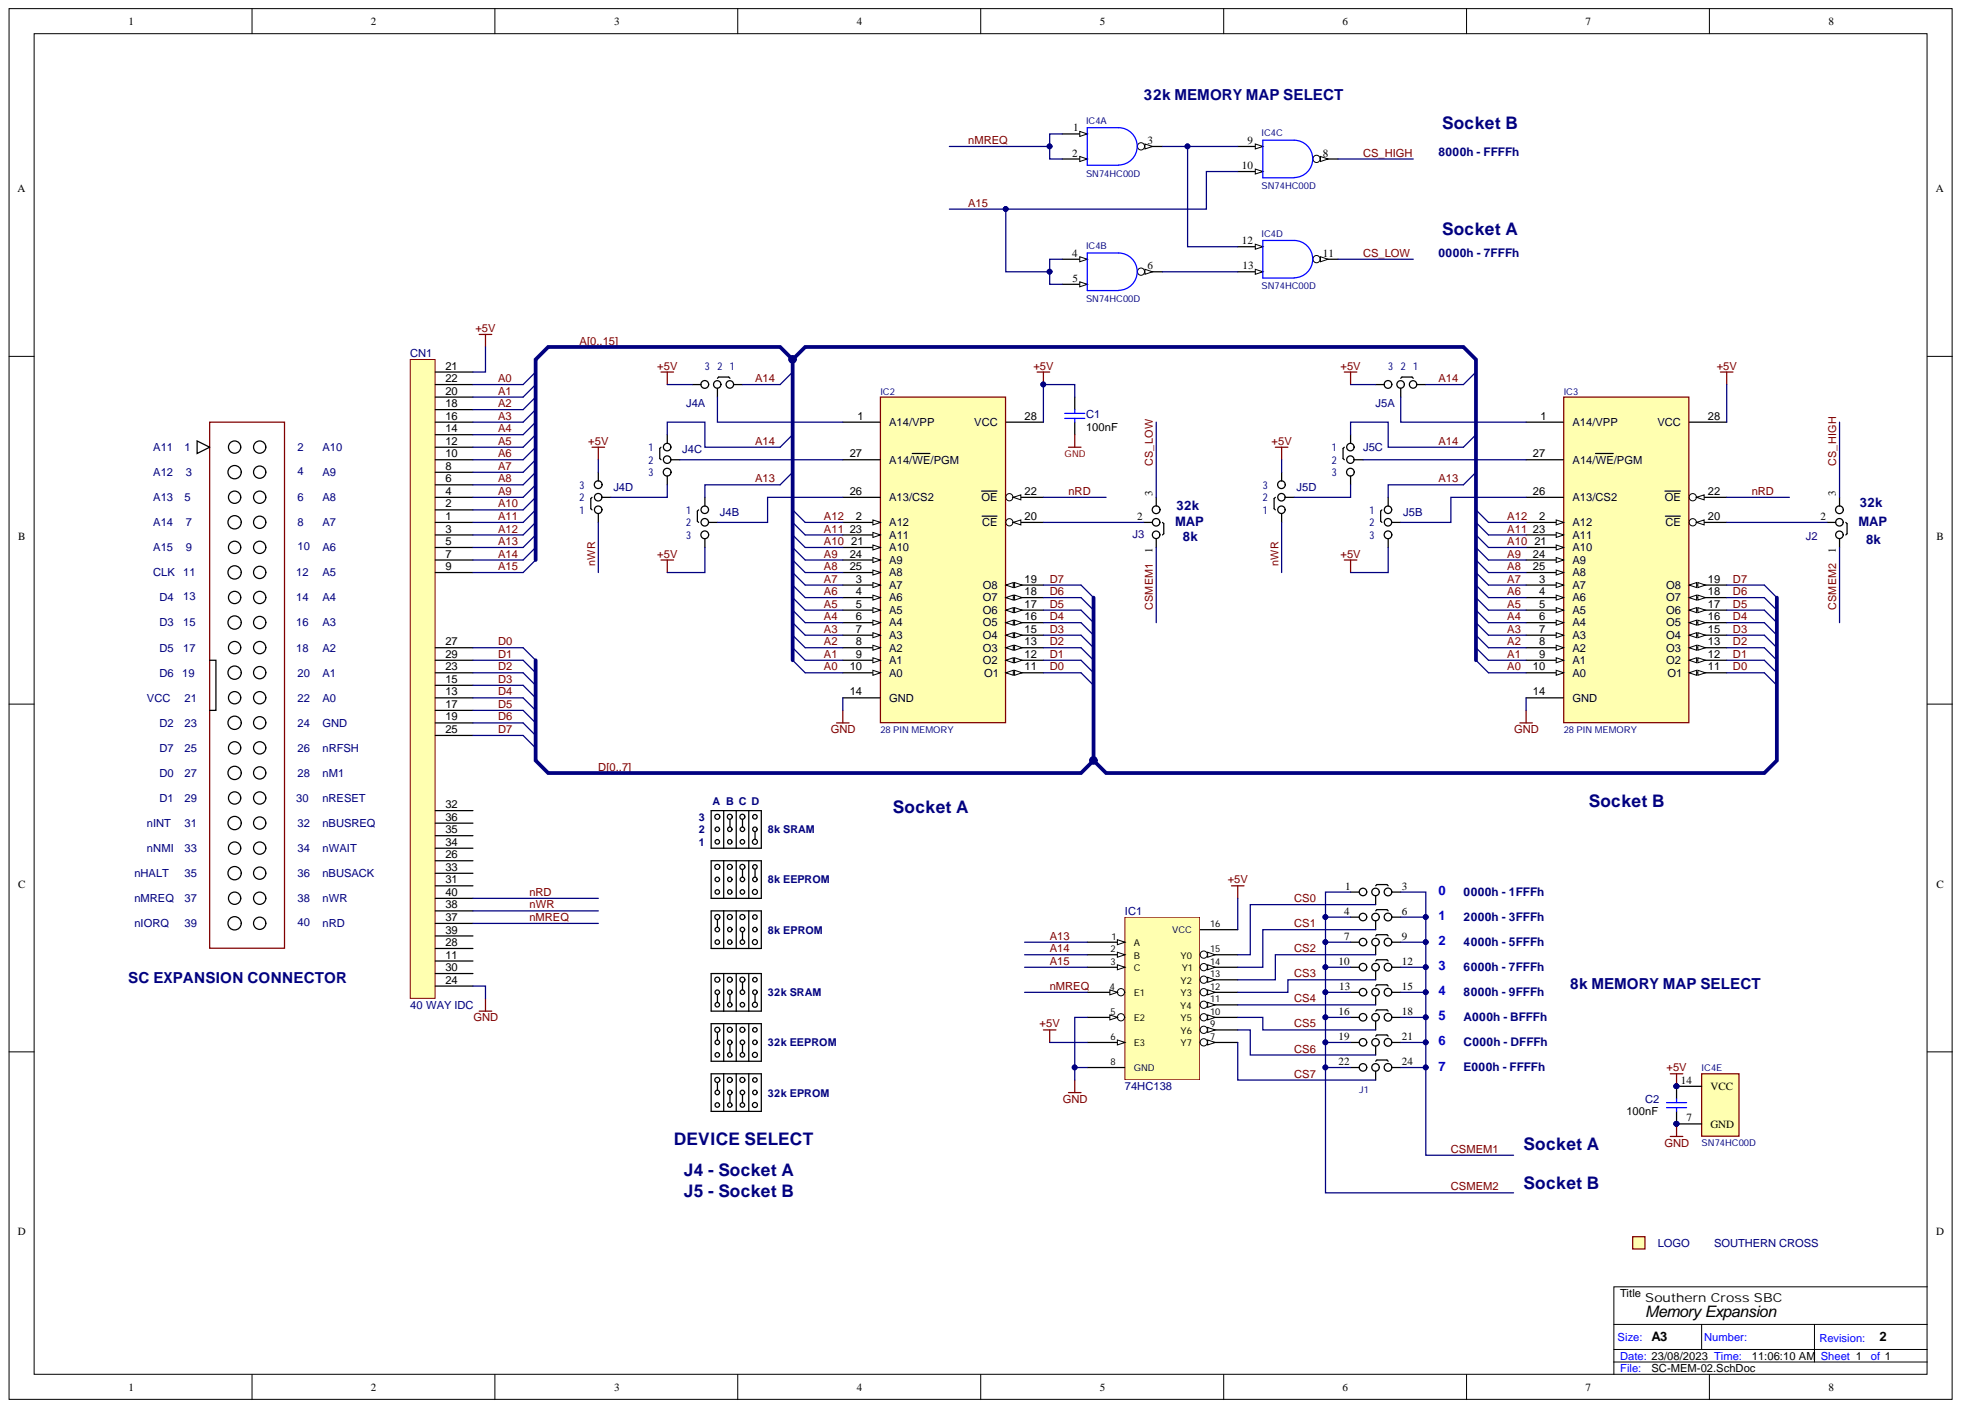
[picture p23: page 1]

GND 8 | CS6 | | 24

CSMEM1

Size: A3 | Number: | Revision: 2
Date: 23/08/2023 Time: 11:06:10 AM | | Sheet 1 of 1

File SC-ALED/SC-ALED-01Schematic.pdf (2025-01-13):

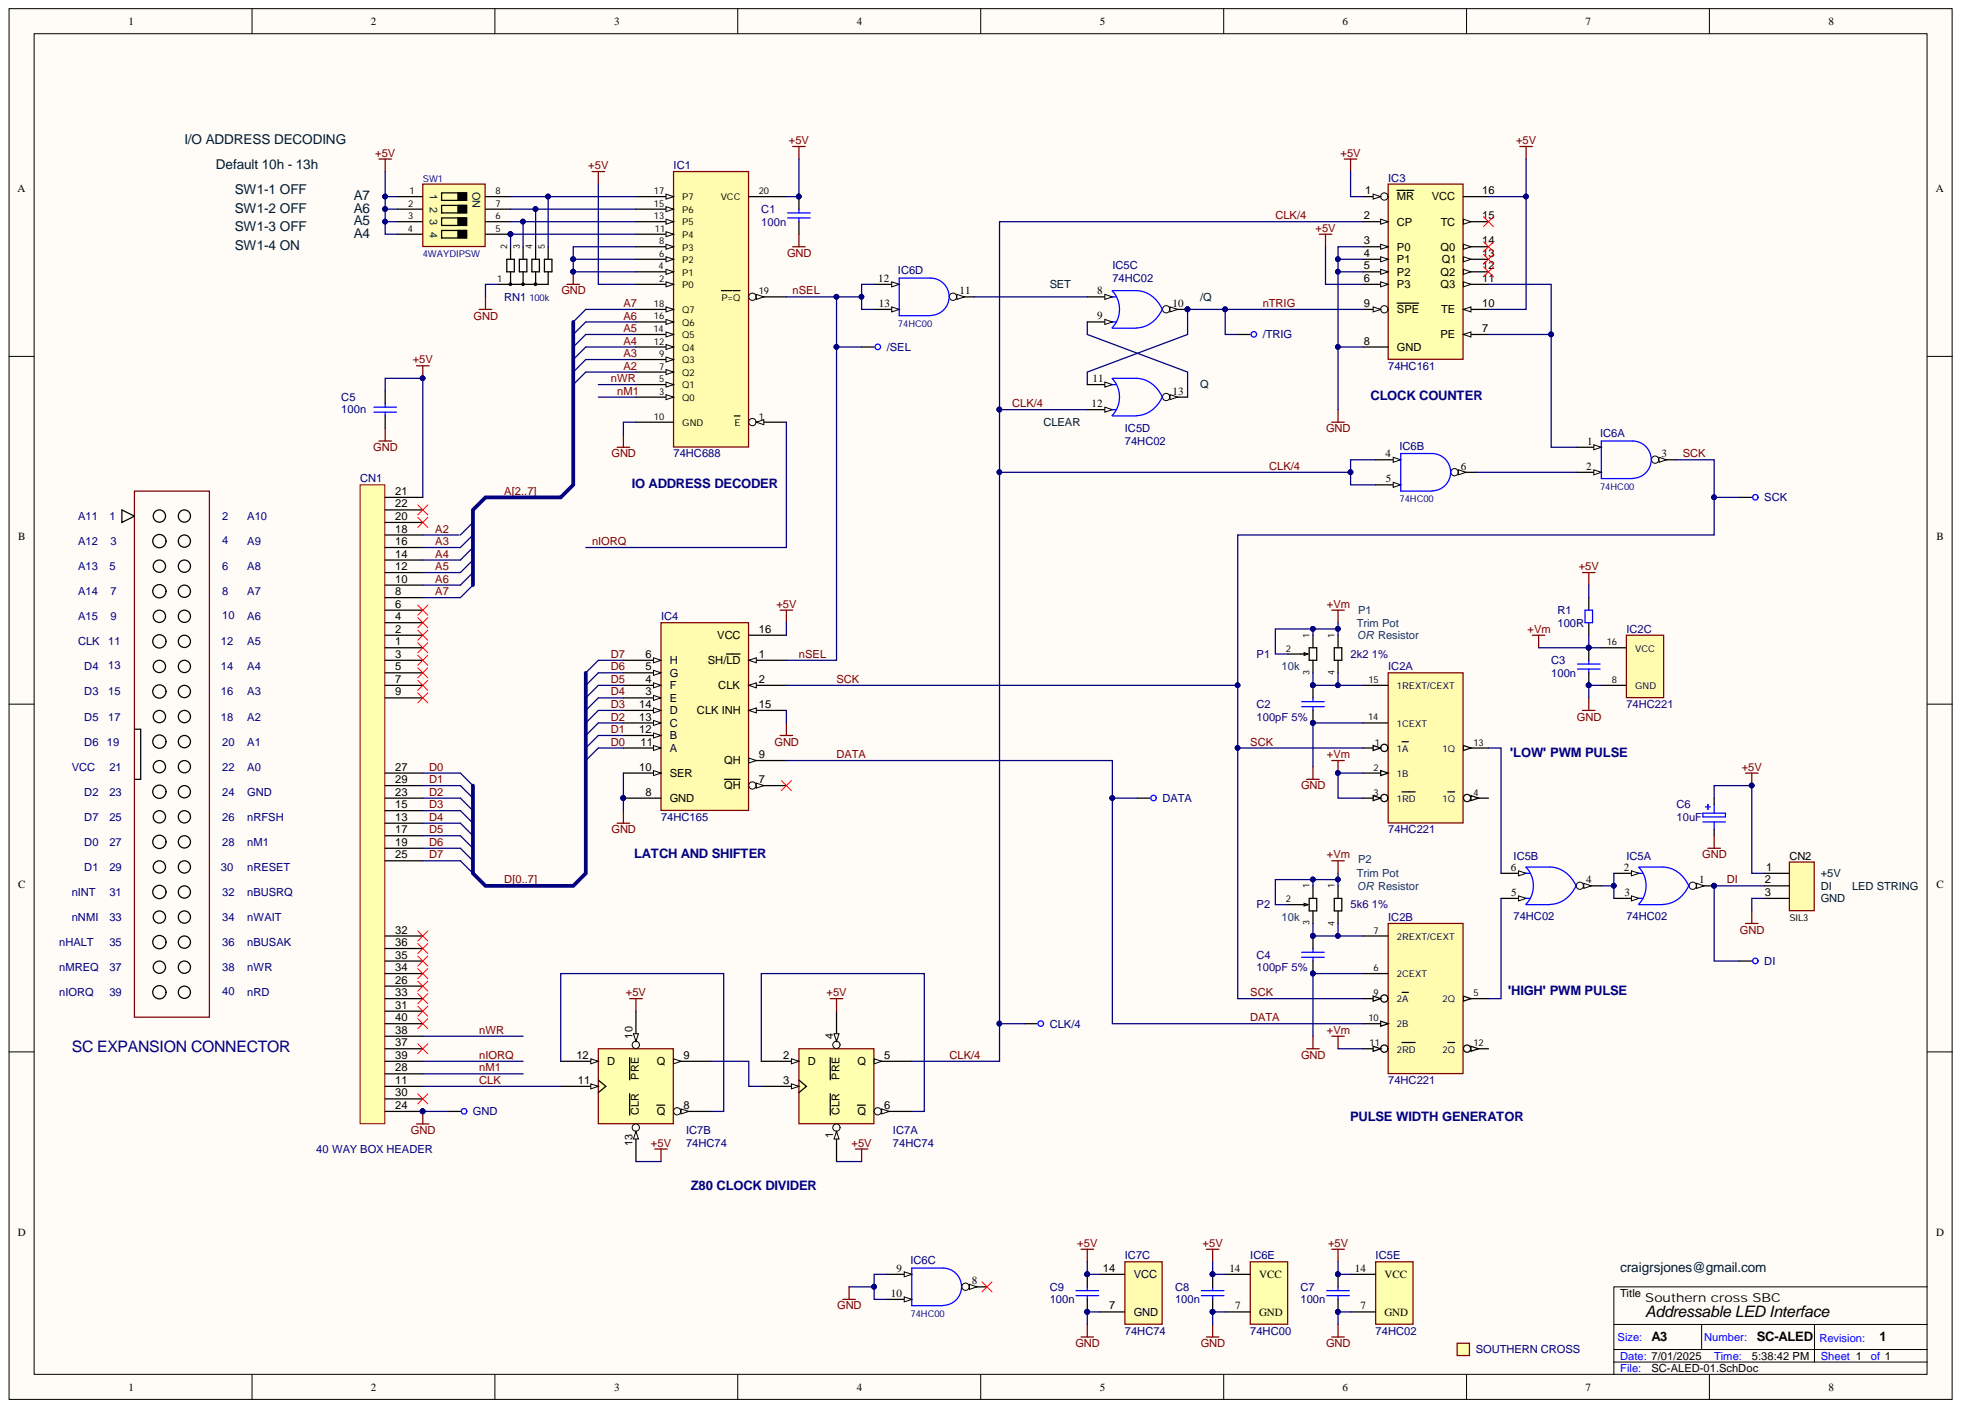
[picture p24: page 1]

Size: A3 | Number: SC-ALED | Revision: 1
Date: 7/01/2025 Time: 5:38:42 PM | | Sheet 1 of 1

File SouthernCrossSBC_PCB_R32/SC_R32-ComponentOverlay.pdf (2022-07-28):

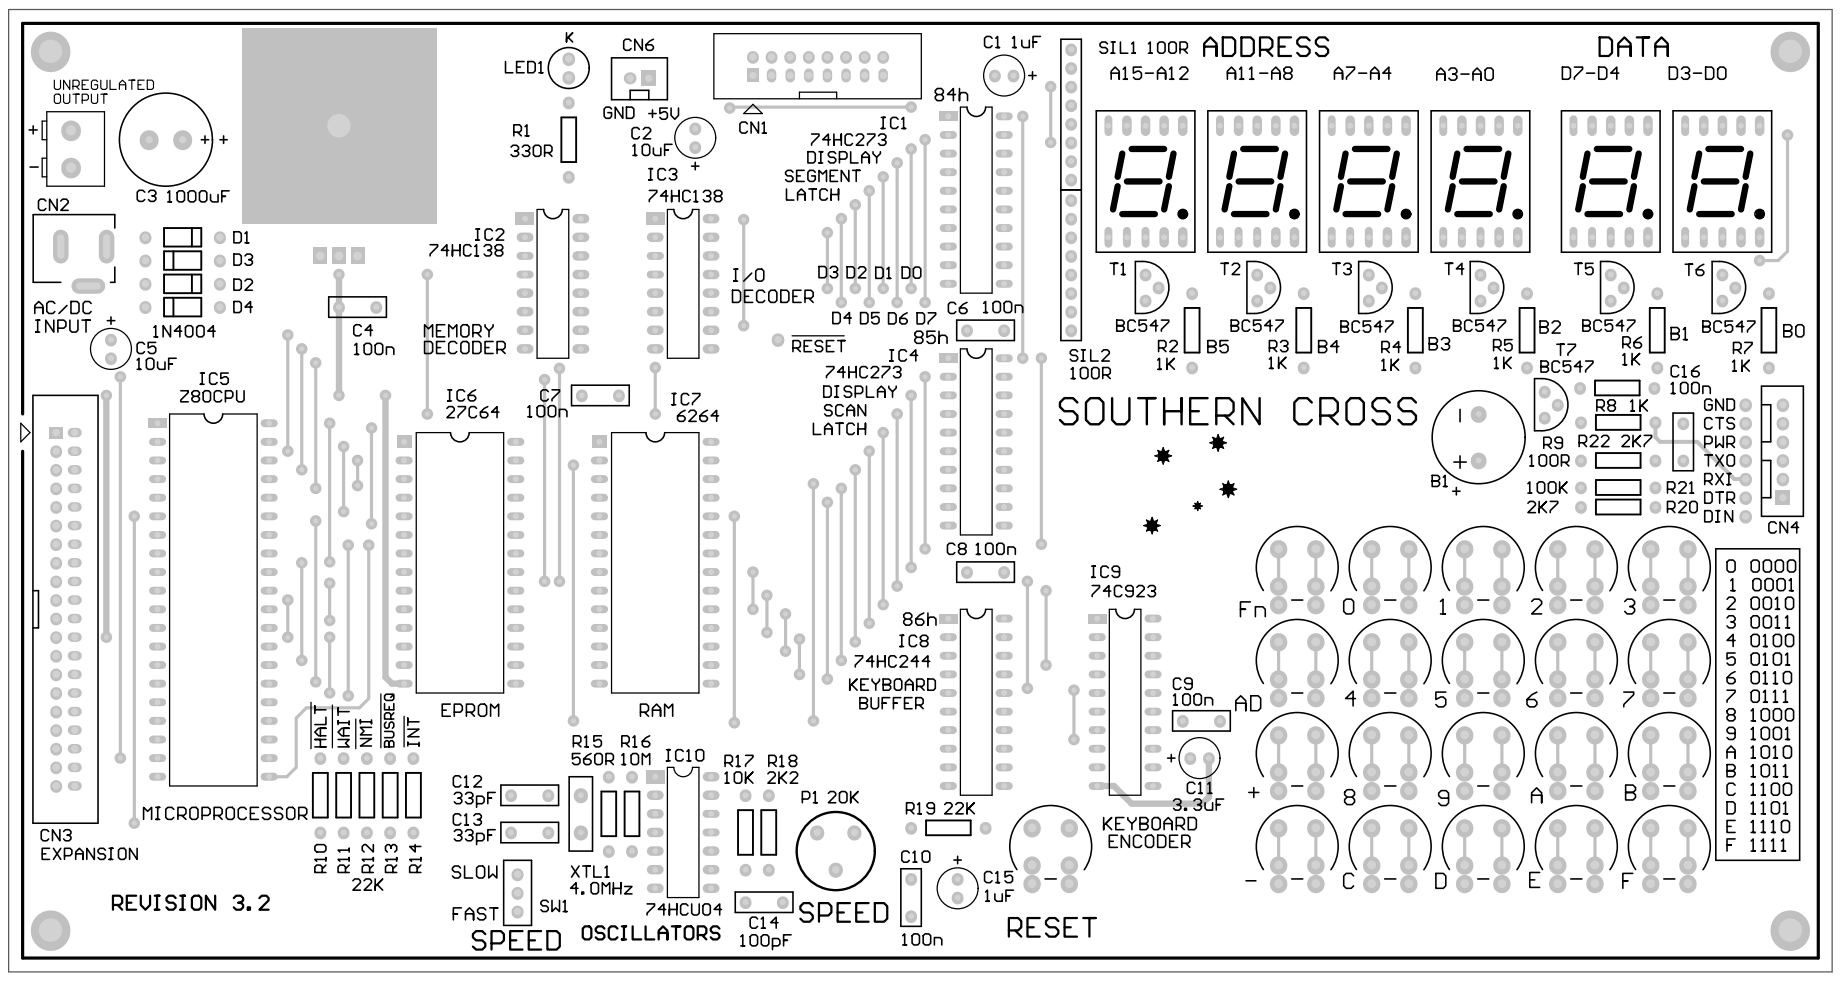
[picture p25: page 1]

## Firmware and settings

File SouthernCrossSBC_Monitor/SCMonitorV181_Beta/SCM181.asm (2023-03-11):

;--------------------------------------------
; S O U T H E R N   C R O S S   M O N I T O R
;--------------------------------------------
;
; WRITTEN BY CRAIG R. S. JONES
; MELBOURNE, AUSTRALIA.
;
; MUSIC AND SOUND CODE FROM
; TALKING ELECTRONICS TEC-1 MONITOR, MON-1
; BY JOHN HARDY AND KEN STONE
;
; 16 BIT MULTIPLY FROM ZAKS 'PROGRAMMING THE Z80'
;
; VERSION : 1.2  01/93  INITIAL RELEASE
; VERSION : 1.21  7/93  CORRECTED RELAY BOARD TEST CODE
;
; Version 1.3  02/2003  ADDED SOFTWARE SCANNED KEYBOARD (UNRELEASED)
; Version 1.4  03/2021  MADE INTELH A SYSTEM CALL, REMOVED CANCEL FUNCTIONALITY FROM RXDATA
;
; Version 1.5  06/2021  ADDED SBUG SERIAL MONITOR
;                       ADDED HELP FOR SBUG COMMANDS
;                       ADDED SBUG ROUTINES TO SYSTEM CALLS
;                       MOVED THE STACK DOWN TO 3E00H TO RESERVE SOME MORE ROOM FOR MONITOR VARIABLES
;                       ADDED INITIALISATION CODE FOR KEYTIM
; VERSION 1.6  09/2021  CONDITIONAL ASSEMBLY ALLOWS FOR TARGET TO BE TEC-1F OR SOUTHERN CROSS
; VERSION 1.7  11/2022  CONDITIONAL ASSEMBLY TARGETS TEC-1F, SOUTHERN CROSS, HARDWARE AND SOFTWARE KEYBOARDS
; VERSION 1.8  03/2023  ADD 'UPDATE','SCBUG' TO SYSTEM CALLS
;                       ADD A SYSTEM CALL TO RETURN THE BASE ADDRESS OF THE RAM VARIABLES
;                       ADDED SYSTEM CALLS FOR STRINGS AND BIT FIELDS TO RETURN BOARD TYPE AND KEYBOARD TYPE
;                       FIXED THE SERIAL GO ROUTINE SO IT RETURNS TO THE SERIAL MONITOR WHEN RET
;                       REMOVE INCH/PUTCH SERIAL REDIRECTION
;                       ADDED A BIT BANG SERIAL INITIALISATION SYSTEM CALL
;                       TRAPPED UNUSED SYSTEM CALLS
;                       CONVERT TEC-1F KEY CODES FOR KEYS ABOVE 'F' INTO SC KEY CODES
;                       SCANKEY ROUTINE RETURNS SHIFT KEY STATUS WITH KEYPRESS
;                       TURN ON THE SPEAKER AT STARTUP
; VERSION 1.81 03/2023  ZERO TERMINATE THE ASCII CONVERSION STRINGS
;                       ADDED KEYBOARD REMAPPING
;
;IF DEFINED THE TARGET IS THE TEC-1F ELSE SC
;#DEFINE TEC-1F
; IF DEFINED USE THE 74C923 KEYBOARD ENCODER ELSE USE SOFTWARE SCANNING
#DEFINE 74C923
;
;---------------
; RAM MEMORY MAP
;---------------
BOTRAM	.EQU	2000H	;BOTTOM OF SRAM
TOPRAM	.EQU	3FFFH	;TOP OF SRAM
;
VARBLS	.EQU	TOPRAM-0FFH	;MONITOR VARIABLES
BUFFER	.EQU	VARBLS-0100H	;GENERAL PURPOSE BUFFER AREA
ISTACK	.EQU	BUFFER-0200H	;INITIAL MONITOR STACK
;
RAMEND	.EQU	ISTACK-0400H	;END OF USER RAM
RAMSRT	.EQU	BOTRAM	;START OF USER RAM
;
; I/O PORT ADDRESSES
;
#IFDEF TEC-1F
;
; TEC-1 I/O ASSIGNMENTS
;
KEYBUF	.EQU	00H	;MM74C923N KEYBOARD ENCODER
SCAN	.EQU	01H	;DISPLAY SCAN LATCH
DISPLY	.EQU	02H	;DISPLAY LATCH
PORT3	.EQU	03H	;ST3 (8X8), STROBE (RELAY BOARD) DATLATCH (DAT BOARD)
PORT4	.EQU	04H	;ST4 (8X8), LCD 'E' (DAT BOARD)
PORT5	.EQU	05H
PORT6	.EQU	06H
PORT7	.EQU	07H	;ENABLE/DISABLE SINGLE STEPPER (IF INSTALLED)
#ELSE
;
; SOUTHERN CROSS I/O ASSIGNMENTS
;
IO0	.EQU	80H	;IO PORT 0
IO1	.EQU	81H	;IO PORT 1
IO2	.EQU	82H	;IO PORT 2
IO3	.EQU	83H	;IO PORT 3
DISPLY	.EQU	84H	;DISPLAY LATCH
SCAN	.EQU	85H	;DISPLAY SCAN LATCH
KEYBUF	.EQU	86H	;KEYBOARD BUFFER
IO7	.EQU	87H	;ENABLE/DISABLE SINGLE STEPPER (IF INSTALLED)
#ENDIF
;
; BIT BANG BAUD RATE CONSTANTS
;
B300	.EQU	0220H	;300 BAUD
B1200	.EQU	0080H	;1200 BAUD
B2400	.EQU	003FH	;2400 BAUD
B4800	.EQU	001BH	;4800 BAUD
B9600	.EQU	000BH	;9600 BAUD
;
; KEY CODES
;
KEYFN	.EQU	10H	;FN OR GO KEY
KEYAD	.EQU	11H	;ADDRESS KEY
KEYINC	.EQU	12H	;PLUS KEY
KEYDEC	.EQU	13H	;MINUS KEY
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

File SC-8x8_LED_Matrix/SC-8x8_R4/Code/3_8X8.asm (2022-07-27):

speed          .equ 10        ;time delay before shift

               .org 2000h

main:          ld de,dis_buff      ;DE is pointer into dis_buff
               ld hl,ASCII_tab     ;HL points to character to display
               ld (code_buff),hl   ;save pointer
loop:          ld hl,(code_buff)   ;looping here: get pointer
               ld a,(hl)           ;put character code in A
               inc hl              ;up pointer to next char
               ld (code_buff),hl   ;save pointer
               cp 0ffh             ;done all characters?
               jr z,scaninit       ;jump if ffh as all converted
               ld l,a              ;put char code into HL
               ld h,0              ;zero H
               push hl             ;put char code into BC also
               pop bc              ;by using the stack
               or a                ;this clears carry flag
               adc hl,hl           ;double char code
               adc hl,hl           ;double char code again (x4)
               adc hl,bc           ;add orginal char code (x5)
               ld bc,char_tab-(20h*5)  ;load BC with base of character
               adc hl,bc           ;table; add offset
               ld bc,5             ;now setup for tranfer of 5 bytes
               ldir                ;from (HL) to (DE); do tranfer
               xor a               ;clear A
               ld (de),a           ;add space to end of char
               inc de              ;next display buffer location
               jr loop             ;do rest of characters

scaninit:      ld a,0ffh           ;mark end of display buffer
               ld (de),a           ;pointer to by DE
scan_in2:      ld hl,dis_buff      ;point HL to start of dis_buff
               ld (ptr1),hl        ;save start
               or a                ;clear carry
               ld de,08            ;now get start for second 8x8
               adc hl,de           ;8 bytes from first
               ld (ptr2),hl        ;save second start
               or a                ;clear carry
               adc hl,de           ;3rd 8 bytes from second
               ld (ptr3),hl        ;save second start

scan_dly:      ld b,speed          ;static scan time
scan_lp1:      push bc             ;save scan time
               ld hl,(ptr1)        ;move pointer to
               ld (aptr1),hl       ;working pointer buffer
               ld hl,(ptr2)        ;second pointer
               ld (aptr2),hl       ;also
               ld hl,(ptr3)        ;
               ld (aptr3),hl       ;
               ld b,80h            ;load B with rotating scan bit
scan_lp2:      ld hl,(aptr1)       ;get first pointer
               ld a,(hl)           ;put display code into A
               inc hl              ;up pointer
               cp 0ffh             ;is this end code?
               jr nz,notend1       ;jump away if not else reset
               ld hl,dis_buff      ;working pointer to start of buff
               ld a,(hl)           ;get display code
               inc hl              ;up pointer
notend1:       ld (aptr1),hl       ;save new working pointer
               out (81h),a         ;output first code to segments
               ld hl,(aptr2)       ;now do all again for second code
               ld a,(hl)           ;put display code into A
               inc hl              ;next
               cp 0ffh             ;end?
               jr nz,notend2       ;jump no
               ld hl,dis_buff      ;else
               ld a,(hl)           ;get first display code
               inc hl              ;up poiner to second
notend2:       ld (aptr2),hl       ;save new pointer
               out (82h),a         ;output second display byte
               ld hl,(aptr3)       ;now do all again for third  code
               ld a,(hl)           ;put display code into A
               inc hl              ;next
               cp 0ffh             ;end?
               jr nz,notend3       ;jump no
               ld hl,dis_buff      ;else
               ld a,(hl)           ;get first display code
               inc hl              ;up poiner to second
notend3:       ld (aptr3),hl       ;save new pointer
               out (83h),a         ;output second display byte
               ld a,b              ;get scan bit in A
               out (80h),a         ;output it to first commons

               ld b,0              ;load B with display on time
               djnz $              ;loop here until delay finished
               ld b,a              ;return scan bit into B
               xor a               ;trick to zero A
               out (80h),a         ;clear commons to prevent ghosts

               rrc b               ;shift scan bit once to the right
               jp nc,scan_lp2      ;jump if not fallen into carry flag
               pop bc              ;else all 8 scanned
               djnz scan_lp1       ;rescan until scan timer = 0
               ld hl,(ptr1)        ;now up first pointer to
               inc hl              ;shift display along
               ld a,(hl)           ;test for end
               cp 0ffh             ;of display buffer
               jr nz,ptr1_ok       ;jump if not end
               ld hl,dis_buff      ;else point to start
ptr1_ok:       ld (ptr1),hl        ;save new pointer
               ld hl,(ptr2)        ;now up second pointer to
               inc hl              ;shift display along
               ld a,(hl)           ;test for end
               cp 0ffh             ;of display buffer
               jr nz,ptr2_ok       ;jump if not end
               ld hl,dis_buff      ;else point to start
ptr2_ok:       ld (ptr2),hl        ;save new pointer
               ld hl,(ptr3)        ;now up second pointer to
               inc hl              ;shift display along
               ld a,(hl)           ;test for end
               cp 0ffh             ;of display buffer
               jr nz,ptr3_ok       ;jump if not end
               ld hl,dis_buff      ;else point to start
ptr3_ok:       ld (ptr3),hl        ;save new pointer
               jp scan_dly         ;jump if not else return


               .org 2100h
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

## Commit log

2021-03-10 Added version 3 files
    [Sc1.GBL, Sc1.GBS, Sc1.GM1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]
2021-09-11 Added serial board
2021-11-09 Added V2 Serial Board
2021-11-10 Added Gerber Files
    [SCSerial2.GBL, SCSerial2.GBS, SCSerial2.GM1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]
2021-11-13 Added GB-Cart
    [SCGBCart10.GBL, SCGBCart10.GBS, SCGBCart10.GM1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]
2022-05-12 Add 8x8 and APU Expansion Boards
    [Sc1.GBL, Sc1.GBS, Sc1.GM1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]
2022-07-27 Re-arranged the folder. Added the R4 8x8
    [Link.stl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]
2022-07-28 Added SCMV16
    [SC_32.GBL, SC_32.GBS, SC_32.GM1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]
2022-07-29 Add Gerbers
    [SC_APU_02.GBL, SC_APU_02.GBS, SC_APU_02.GM1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]
2023-02-20 Changed SC connectors to ribbon cable numbering
2023-08-23 Added SC-MEM
    [SC-MEM-02.GBL, SC-MEM-02.GBO, SC-MEM-02.GBS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]
2023-08-25 Add SC-CPU
    [SC-CPU-02.GBL, SC-CPU-02.GBO, SC-CPU-02.GBS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]
2024-06-19 Add SC-BP
    [SC-BP-02.GBL, SC-BP-02.GBO, SC-BP-02.GBS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]
2024-08-23 Added SC Version 3.3
    [SC_33_3.GBL, SC_33_3.GBO, SC_33_3.GBS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]
2024-08-27 update to pcb rev 3.3
2024-12-29 Added KiCad template
    [SC_Template.kicad_pcb, SC_Template.kicad_sch]
2025-01-15 Add readme to sC-BP
    [SC-BPCardGuide.stl]
2025-01-15 Add Overlay and BOM
2025-03-13 Updated 8x8 schematic
2025-04-20 Added LCD project
    [SC-LatchLCD.obj]
